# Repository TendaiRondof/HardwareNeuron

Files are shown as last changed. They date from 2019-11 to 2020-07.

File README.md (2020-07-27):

# HardwareNeuron
Eine Brufsmaturitätsarbeit für die BBW Winterthur.

## Abstract
### Deutsch
In dieser BMA stellen wir, Tendai und Malik, uns die Frage, ob es möglich ist, mit simplen elektronischen Bauteilen eine Schaltung zu entwerfen, die bestimmte, elementare Logik erlernen und anschliessend wiedergeben kann. Um dies zu erreichen, verwenden wir das Modell eines Neurons. Wir erläutern Struktur und Funktion des biologischen und des informatischen Modells. Schliesslich fällt unsere, ausführlich begründete Entscheidung auf das spiking neural Network. Das die Version des informatischen Modells, welches dem bioligischen am nächsten kommt. Danach nähern wir uns mittels mathematischen Formeln, basierend auf dem spiking neural Network, den Funktionen an, welche die Schaltung erfüllen muss. Darauffolgend werden die Teilfunktionen erklärt und es wird erläutert, wie unsere Schaltung sie bewältigen soll. Die Messungen des Prototypen zeigen, dass die Vorwärtsrechnung, also das wiedergeben des gelernten, funktioniert. Das Problem ist, dass bei unserem Endprodukt nichts funktioniert, da die Leiterbahnen auf dieser Version sehr kurzschlussanfällig sind und wir keine Zeit mehr hatten, alle Kurzschlüsse zu beheben.
### English
In this BMA we, that’s Malik and Tendai, ask ourselves, wether or not it’s possible, to design an electrical circuit, which can learn certain, elementary logic and replicate it subsequently. In order to reach this, we use the model of a neuron. We explain structure and function of the biological and informatical model. In the end, our decision falls onto the spiking neural network. That’s the informatical model, which comes closest to the biological one. Then, we draw up the functions, that our circuit has to implement, through mathematical formulas. After that, the purposes of the smaller subcircuits, we designed, is explained. In the measurements of the Prototype it is shown, that the replication of logic works. Unfortunately the learning itself doesn’t. Besides of that, our final product doesn’t work at all, because there are shortcircuits all over the print and we didn’t have time, to repair them all.

Von Tendai Rondof und Malik Schneider

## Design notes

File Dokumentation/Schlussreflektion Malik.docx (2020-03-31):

Schlussreflektion zur BMA Hardware Neuron

Ich war mit dieser BMA bereits überfordert, als es noch um die Themenwahl ging. Ich wusste, dass wir wahrscheinlich ungefähr 100 Stunden in dieses Projekt stecken müssten, um es befriedigend fertigzustellen.

Das Thema würde also von riesigem Gewicht sein. Wer will sich schon 100 Stunden mit etwas auseinandersetzen, was ihn nicht interessiert. Das erste Mal, als wir uns für ein Thema entschieden, kamen wir auf das Thema Videospiele und ihre Physik. Diese wollten wir in unserem Projekt analysieren. Wir haben uns nach einer Zeit aber dagegen entschieden, da wir dachten, dass diese Arbeit zu nichts führen würde.

Dann begannen wir die Arbeit am eigentlichen BMA-Projekt: dem Hardware Neuron. Die Idee war eine elektrische Schaltung zu entwickeln, welche die Lernprozesse eines Neurons nachahmen konnte. Wir entschieden uns dafür, weil es ein festes Ziel war, was wir anstreben konnten und es uns interessierte. Ich denke nach wie vor, dass es die richtige Entscheidung war, aus den zuvor genannten Gründen.

Der Zeitplan, den wir erstellt hatten, wurde in den ersten Monaten sehr gut eingehalten. Wir waren sogar ein grosses Stück vor dem Zeitplan. Das war, als wir das Schema der Schaltung im Prinzip vollendet hatten und dachten, wir könnten uns jetzt ausruhen. Jetzt wissen wir jedoch, dass es am besten gewesen wäre, gleich erste Prototypen zu erstellen. Wir starteten damit nämlich erst knapp einen Monat vor der Abgabe. Und konnten auch nur am Wochenende daran arbeiten. Das bedeute für uns, vier Wochen lang keinen einzigen freien Tag. Trotz diesen Anstrengungen, reichte die Zeit am Ende dann doch nicht. Das war sehr ärgerlich. Dafür haben wir unsere Arbeit ziemlich gut dokumentiert, meiner Meinung nach. Wir konnten alle Vorgänge des Neurons erklären und die Annäherung vom Modell zur Schaltung ist ausführlich und klar. Auch die Gesamtstruktur mit allen nötigen Verzeichnissen ist vorhanden.

Obwohl unser Produkt nicht den geplanten Endstatus erreicht hat, bin ich gesamthaft gesehen mit unserer BMA zufrieden.

Malik Schneider 11.02.2020

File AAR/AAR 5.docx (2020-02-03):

# 15 minütiges After Action Review

# 1. Was sollte erreicht werden? (Sollzustand/Ziel: anspruchsvoll, aber realistisch, konkret) [1 Minute]

Funktionierender Print der Neuronschaltung, schriftlicher Kommentar vollständig

# 2. Was haben wir (nicht) erreicht? (Istzustand: kurz, präzise, vollständig) [2 Minuten]

Schriftlicher Kommentar vollständig, Print funktioniert nicht lediglich der Prototyp in begrenztem Masse

# 3. Warum haben wir es (nicht) erreicht? (Abweichungsanalyse: selbstkritisch, vielfältig) [4 Minuten]

In den letzten paar Wochen haben wir am Prozess und in der Planung nichts falsch gemacht. Wir haben uns die wenige Zeit die wir hatten klar eingeteilt. Leider ist die Bestellung des letzten Prints nicht planungsgemäss angekommen und und der Print den wir deswegen selber in der MSW machen mussten nahm viel zu viel Zeit in Anspruch, funktionierte am Ende dann aber doch nicht. Es wäre zwar möglich gewesen, ihn zu reparieren, aber dafür hatten wir dann endgültig keine Zeit mehr.

# 4. Was können wir daraus lernen? (Handlungsmassnahmen: konkret, realistisch, ausgearbeitet) [8 Minuten]

Wir können daraus lernen, dass man eine solch gigantische Arbeit mit viel Zeitreserven planen sollte.Vor allem bei einem Produkt mit dieser Komplexität.

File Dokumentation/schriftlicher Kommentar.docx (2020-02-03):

Berufsmaturitätsarbeit 2019-2020

Hardware-Neuron

Tendai Rondof / Malik Schneider

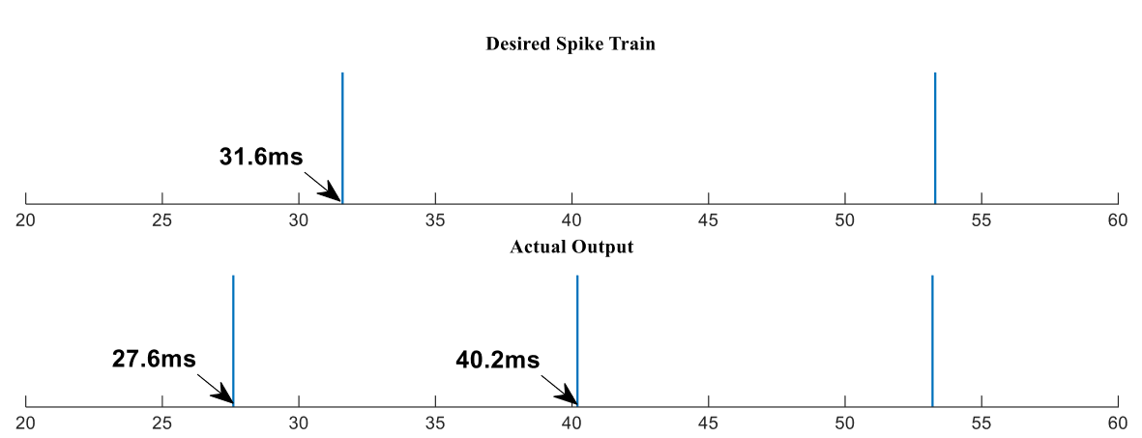
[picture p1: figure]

S(t)

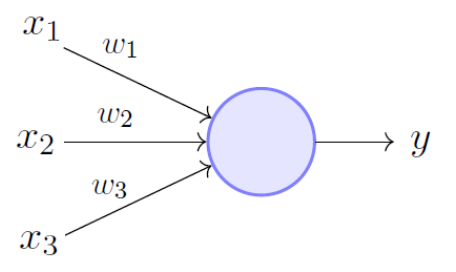
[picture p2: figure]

U_a (t)

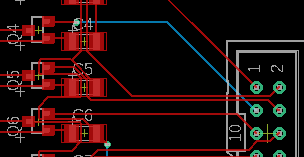
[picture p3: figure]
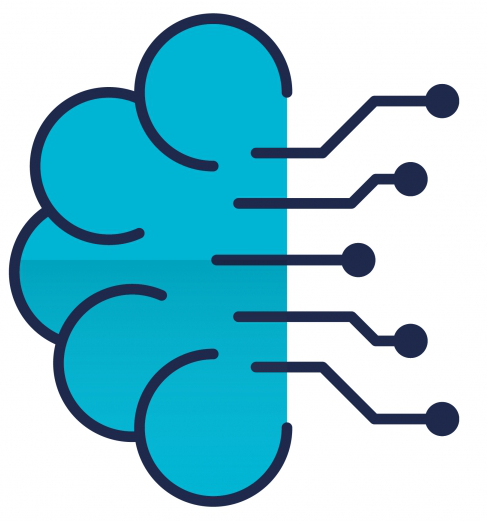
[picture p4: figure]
Bildergebnis für artificial intelligence icon

# Vorwort

Seit einiger Zeit boomt das Interesse an künstlichen Intelligenzen und neue Ideen, wie sie umgesetzt werden können, sind hochgefragt. Wir erwarten nicht dass wir mit einem Analogen Neuron das Rad neu erfinden, jedoch gelingt es uns einen Weg zu beschreiten der bis jetzt noch niemand gedacht hat.

## Tendai

Ich habe dieses Thema ausgewählt, weil Künstliche Intelligenzen mich seit Jahren interessieren. Durch dieses Projekt kann ich den Wunsch ein Neuron auf Hardwarebasis zu erstellen, endlich erfüllen.

## Malik

Ich habe das Thema gewählt, weil darin zwei meiner grössten Interessensgebiete vereinigt sind: Die Elektronik und die Neurowissenschaft. Vor allem bei letzterem kann ich hiermit mein Wissen erweitern und vertiefen. In der Elektronik kann ich vor allem mein bereits bestehendes Wissen anwenden und trainieren, was meinem späteren Berufsleben ein wenig zu gute kommen könnte.

## Danksagungen

Wir möchten unserem Abteilungsleiter, Oliver Schneider, in der MSW danken, welcher uns erlaubte an den Wochenenden in der MSW an unserer BMA zu arbeiten. Ohne seine Hilfe hätten wir unser Produkt sicher nicht rechtzeitig beenden können.

Daniel Büchler, Abteilungsleiter für die ersten beiden Lehrjahre der Elektroniker in der MSW hat uns freundlicherweise den Fräsbohrplotter zu Verfügung gestellt. Dieser Umstand hat unsere Arbeit ungeheuer beschleunigt.

# Abstract

# Einleitung

Das Ziel unserer BMA ist es, den Vorgang des Lernens mit greifbaren elektrischen Bauteilen zu simulieren. Dieser Aspekt allein hat schon eine gewisse Faszination an sich. Unter Machine-Learning versteht man etwas extrem Komplexes, was sich auf Softwareebene abspielt. Für eine Künstliche Intelligenz sind riesige Mengen an Daten Nötig um ihr etwas beizubringen. Aber wie so vieles, lässt sich auch eine Intelligenz, ob sie jetzt künstlich ist oder nicht, herunterbrechen auf ihre Elementarsten Teile. Beim Menschen sind es die Neuronen, bei der Maschine elektrische Schaltkreise. Unser Produkt ist ein wenig von beidem. Denn wir simulieren das menschliche Neuron mit einer elektrischen Schaltung.

Aufgrund unseres Lehrberufs, Elektroniker, setzten wir den Fokus auf die Funktionalität und nicht auf Biologische Richtigkeit. Das bedeutet, dass wir versuchten die chemischen Prozesse elektronisch zu imitieren. Es fielen zwar viele der Biologischen Aspekte eines Neurons weg, jedoch bleibt der Kern des ganzen schlussendlich bestehen: das Lernen.

Um die Printplatte herzustellen, auf welcher wir unsere Schaltung aufgebaut haben, verwendeten wir den MSW-Internen Fräsbohrplotter, welcher uns die ersten Prototypen in höchstgeschwindigkeit zur Verfügung stellen konnte.

Die Frage die wir uns mit dieser BMA beantworten wollen lautet:

Was ist eine Möglichkeit ein Neuron (Nervenzelle) mittels Elektronischen teilen zu realisieren und kann damit eine selbstlernende elektrische Schaltung (“Neuron”) erstellt werden?

Um diese Frage dreht sich die ganze Arbeit unserer BMA. Darum auch der Name Hardware-Neuron. Unser Endprodukt wird Ausschlisslich aus Elektronischer Hardware bestehen. Mit unserem Endprodukt werden wir uns den ersten Teil der Frage also selbst beantworten.

Zu Beginn des Hauptteils wird das Konzept zur Lösung des Problems in all ihren Details und mathematischen Formeln erklärt. Danach wird die Schaltung erklärt, die wir erstellt haben und nach den zuvor erläuterten Funktionen arbeitet. Darauf folgen das Design des Prints auf EAGLE und die Auflistung der Bauteile welche auf den Print gehören.

# Hauptteil

# Theorie

## Grundlage der Problematik

Es soll eine Schaltung erstellt werden, die Mathematische Berechnungen eines Neurons imitiert. Dadurch kann eine lernende Schaltung entwickelt werden, die dynamische bzw. lernende Schaltkreise ermöglichen. Zudem wird die Rechenzeit für ein Neuron reduziert.

Als lernen ist zu verstehen, dass die Schaltung berechnet, wie sie welche Eingänge verarbeiten soll. Das passiert, indem der Nutzer am Eingang Daten anlegt und gleichzeitig einen Sollwert für den Ausgang definiert. Mit der Zeit lernt also die Schaltung, wie sie die Eingangsdaten verarbeiten soll und wie sie darauf reagieren soll.

## Testbedingungen

Damit das Folgende auch gut verstanden werden kann, eine kurze Erklärung zu den Fachbegriffen. In der Elektronik bzw. Digitaltechnik wird mit dem Binären Zahlensystem gearbeitet, diese Zahlen werden aus Einsen und Nullen gebildet.

Jede 0/1 hat einen Zahlenwert den sie repräsentiert. Im binärsystem wird die Wertung von rechts nach links pro Stelle verdoppelt. D.h. die erste Ziffer von rechts steht eins, die zweite für zwei, die dritte für 4 usw.. Steht eine Eins an der Stelle wird die jeweilige Wertung dazu addiert, steht da eine Null, dann nicht.

Bsp.:

0001 entspricht im Dezimalsystem der Zahl 1. Weil: (0*8)+(0*4)+(0*2)+(1*1)=1

0010 entspricht der Zahl 2. Weil: (0*8)+(0*4)+(1*2)+(0*1)=2

0011 entspricht der Zahl 3. Weil: (0*8)+(0*4)+(1*2)+(1*1)=3

0100 entspricht der Zahl 4. Weil: (0*8)+(1*4)+(0*2)+(0*1)=4

Usw.

In der Praxis entspricht die 1 einer Spannung von 5 Volt (auch «High» genannt) und die 0 einer Spannung von 0V (auch «Low» genannt).

Um diese Informationen in der Elementarsten weise zu verarbeiten werden Drei Grundgatter verwendet:

AND:

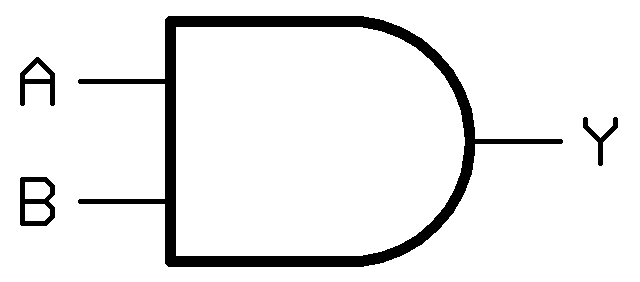
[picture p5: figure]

(Quelle : https://de.wikipedia.org/wiki/Datei:Logic-gate-and-us.png)

A | B | Y
0 | 0 | 0
0 | 1 | 0
1 | 0 | 0
1 | 1 | 1

Das AND-Gate verknüpft die Eingänge (A & B) so, dass der Ausgang (Y) nur einem «High» entspricht, wenn die A und B zur gleichen zeit auch «High» sind. Jede andere Kombination führt zu einem «Low» am Ausgang.

OR:

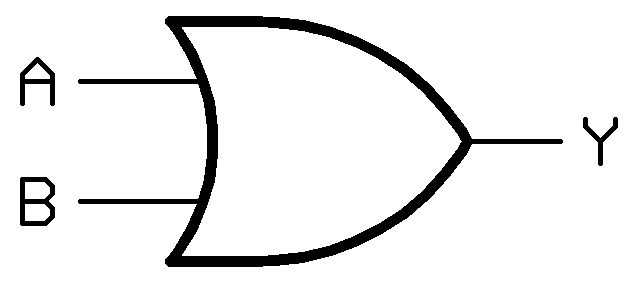
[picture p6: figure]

(Quelle : https://de.m.wikipedia.org/wiki/Datei:Logic-gate-or-us.png)

A | B | Y
0 | 0 | 0
0 | 1 | 1
1 | 0 | 1
1 | 1 | 1

Das OR-Gate verknüpft die Eingänge (A & B) so, dass der Ausgang (Y) einem «High» entspricht, wenn mindestens einer der Beiden Eingänge «High» ist.

NOT:

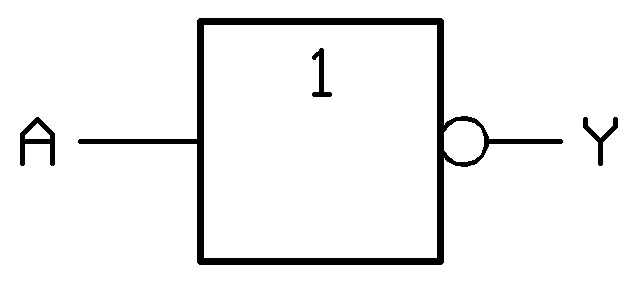
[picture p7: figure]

(Quelle : https://de.wikipedia.org/wiki/Datei:Logic-gate-inv-iec.png)

A | Y
0 | 1
1 | 0

Das NOT-Gate besitzt nur einen Eingang (A). Das Gatter macht nichts anderes, als das Gegenteil vom Eingang auszugeben.

### Möglichkeiten

Um zu überprüfen ob das Neuron auch lernt, soll es die Aufgabe von logischen Gattern (AND, OR) übernehmen bzw. lernen. Um zu überprüfen, ob das Neuron in der Lage ist zu merken, wenn ein Eingang nicht benötigt wird, wird neben den notwendigen Eingängen auch noch ein überflüssiger Eingang benutzt, der Ignoriert werden soll. Wenn dies zuverlässig funktioniert, kann man davon ausgehen, dass das Neuron in der Lage ist, bedingt komplexe Zusammenhänge zu approximieren und wichtige von nicht wichtiger Information zu unterscheiden.

### Unmöglichkeiten

Da das Neuron auf keinen Fall in der Lage ist Invertierungen (NOT-Gatter) zu imitieren, sind Kombinationen auf der Basis: «Wenn ein Eingang nicht eingeschaltet ist, dann…». Von vorherein ausgeschlossen und unmöglich für das Neuron zu erlernen.

Um es in technischer Sprache zu sagen, das Neuron ist nicht in der Lage XOR, XNOR, NAND, NOR oder NOT Gatter zu erlernen, da nach dem Aufbau des Eingangs (Inputs) immer ein Stromzufluss herrschen muss.

## Grundlegendes Model eines Neurons

### Biologisch

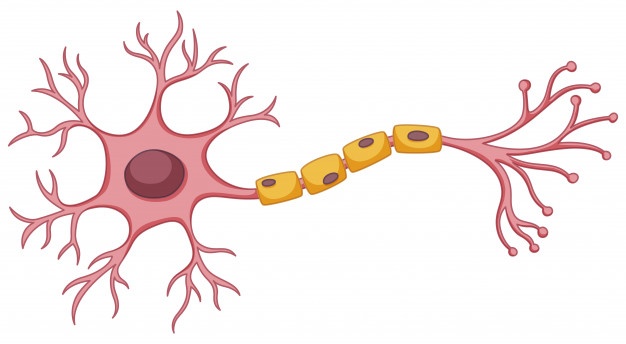
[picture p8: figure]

Abbildung 1

Das Neuron ist eine Nervenzelle, die nahe zu überall in unserem Körper vorhanden ist. Ihr wichtigster Einsatzort ist das Gehirn.

## Bedingungen/Einschränkungen

Es gibt gewisse Probleme bei der Übersetzung vom Modell in die reale Welt. Zum einen ist die Praxis nie perfekt. Bauteile haben Toleranzen, Unendlichkeiten gibt es nicht und es ist nicht möglich Spannungen auf eine einfache Art und Weise zu multiplizieren.

Die gewünschte Formel wird auch nicht in einer reinen Form vorkommen.

## Typ des Neurons (Vorteile gegenüber anderen Methoden)

Als Grundprinzip benutzen wir das Modell eines Spiking-Perceptrons, was ein einzelnes Neuron mit einem pulsierenden, digitalen Ausgang darstellt.

Der Vorteil gegenüber anderen Methoden ist, es kommt der Biologie am nächsten und die Rückrechnung ist mit einzelnen Transistoren machbar.

Der Nachteil ist, es ist zeitabhängig. Was bedeutet, dass zeitlich alles gut aufeinander abgestimmt sein muss.

## Mathematischer Ansatz vorwärts Rechnung

Die Grundformel für den Kern des Neurons ist:

C(dU_c (t))/(dt)=-(U_c (t))/(R_0)+(∑_i^n (U_(x_i) (t))/(R_(T_i) (U_(c_(T_i)) (t))))+I_(bias) (t)-(U_c (t))/(R_(disc) (U_a (t)))

(Formel 1) Quelle: 7146.pdf

U_c :Die spannung am Kernkondensator

C:Kapazität des Kernkondensators

R_0 :Entladungs Widerstand am Kernkondensator

n:Anzahl eingänge

U_(x_i) :Sapnnung Am eingang i

R_(T_i) :Funktion des Transitor-Widerstands in abhängikeit der Spannung U_(c_(T_i))

U_(c_(T_i)) : Spannung des Kondensators am Gate des Transitors

I_(bias) :Strom des Statischen 5V eingangs

R_(disc) : Widerstand des Entladungstransitors

Wenn der Kern-Kondensator eine Gewisse Spannung (U_(ref) ) erreicht wird ein «Spike» erzeugt, was am Ausgang ausgegeben wird. Dieser «Spike» wird durch eine Aktivierungsfunktion erzeugt.

## Aktivierung

Y(t)= d/(dt)(max(U_c (t),U_(ref) )*V_(cc) )

U_c :Kernkondensator Spannung

U_(ref) :Statische Referenz Spannung

V_(cc) :Speise Spannung des Prints

Y : Ausgabe der Schaltung

Sobald der Spike erzeugt wird, wird U_c über den Discharge-Transitor auf 0V gezogen. Was zur Folge hat, dass wenn der Input dauerhaft auf 5V gestellt ist, sich ein «Spike Train» mit einer Festen Frequenz bildet.

## Fehlerberechnung

Damit das Neuron überhaupt etwas lernt, muss eine Art Feedback vom Nutzer oder von der Umgebung kommen. Dafür wird ein Rückgabewert ( S ) verwendet. Mit diesem Rückgabewert kann die Gewichtung 1/(R_(T_i) (U_(c_(T_i)) (t))) angepasst werden, indem U_(c_(T_i)) verändert wird.

(dU_(c_(T_i)) (t))/(dt)=1/(V_(cc)^2 *R_(LR))*U_(X_i) (t)*|S(t)-Y(t)|*(|S(t)-Y(t)|-U_(c_(T_i)) )

(Bild 2) Quelle: 7146.pdf

U_(c_(T_i)) : Spannung des Kondensators am Gate des Transitors

C_(T_i) : Kondensator am Gate des Transistors

U_(x_i) : Spannung am Eingang i

R_(LR) : Widerstand der die Ent-/Lade Geschwindigkeit des Kondensators C_(T_i) angibt (Lern- Schrittgeschwindigkeit)

V_(cc) :Speise Spannung des Prints

S : Ziel Spike-Train, dass das Neuron erreichen soll

Da S und Y zeitbegrenzte Pulse sind, wird der Kondensator nur ein klein wenig entladen/geladen was den Transistor am jeweiligen Eingang etwas mehr sperrt oder leitet. Dadurch können alle Inputgewichte über die Zeit so eingestellt werden, dass S(t) dem Ausgang U_a (t) entspricht.

Dies ist natürlich nur bis zu einer gewissen Komplexität möglich. Vor allem, da die Eingangsströme nicht negativ sein können.

## Problematik von Theorie und Praxis

Die Grösste Problematik ist, dass das Speichern von Analogen Spannungen nur sehr schlecht geht und sehr störungsanfällig ist. Man kann die Schaltung etwas Stabilisieren, indem man den Print so gut wie möglich isoliert um jeglichen Energieverlust über benachbarte Leitungen zu vermeiden.

## Blockschaltbild

Output

Schaltung

Stecker

- 3 Eingänge

- Sollwert für Output

- Rückrechnung Ein/Aus

Abbildung 2

# Erklärung der Funktion

## Ganzes Neuron

Abbildung 3

Der Eingang (Input) verarbeitet die Spannung an den Eingängen X_0 bis X_2 und summiert sie. Das Zentrum (Core) des Neurons speichert die Werte des Eingangs über die Zeit, bis die Aktivierung (Activation) einsetzt und das Zentrum zurückgesetzt wird.

Der Eingang S bei der Fehlerberechnung (DeltaCalcV2) entspricht dem Sollwert zu Trainingszeiten. Der Ausgang Y bei der Aktivierung wird zu jedem Zeitpunkt beim Training mit dem Sollwert mittels der Fehlerberechnung verarbeitet und der Eingang angepasst.

Das Neuron lernt somit über Zeit und der Eingang wird bei jedem Fehler um einen konstanten minimalen Schritt-Wert angepasst, um ein Schwingen um den Idealwert zu vermeiden und um das Neuron robuster gegen einzelne Fehler in den Trainingsdaten zu machen.

## Input

Abbildung 4

Die Eingangsspannungen X_0 bis X_2 werden über die, zum Teil leitenden, Transistoren in spezifische Ströme umgewandelt und am Ausgang summiert.

Die Spannungen an den Kondensatoren bestimmen, wie stark die Transistoren durchsteuern. So kann der Widerstand der Transistoren kontrolliert werden. Die Spannung an den Kondensatoren wird über die Fehlerberechnung verändert.

Im mathematischen Sinne entspricht diese Teilschaltung dem Abschnitt

(∑_i^n (U_(x_i) (t))/(R_(T_i) (U_(c_(T_i)) (t))))+I_(bias) (t)

Aus der Formel für die Vorwärtsrechnung.

Der I_(bias) (t) kommt von dem Transistor Q_7 , der direkt an V_(cc) angeschlossen ist.

### DeltaApply

Abbildung 5

Diese Teilschaltung ist für das Anpassen der Spannungen am Kondensator zuständig. Jeder Eingang besitzt eine solche Teilschaltung. Der Eingang Delta bestimmt, ob der Core-Kondensator geladen oder entladen wird. Enable schaltet mit der Spannung am Transistor den Rückrechnungsvorgang ein oder aus. Der Eingang X sagt der Schaltung, ob der Eingang der Gesamtschaltung überhaupt aktiv war.

Diese Teilschaltung ist die Umsetzung des Formelabschnittes 1/(V_(cc)^2 *R_(LR))*U_(X_i) (t)*E*(D-U_(c_(T_i)) ) , wobei E dem Enable-Eingang, U_(X_i) dem Eingang X und D dem Delta Eingang entspricht.

## Core

Abbildung 6

Der Core besteht hauptsächlich aus einem Kondensator C , welcher über den Eingang a aufgeladen wird. Für den Fall, dass keine Signale über die Eingänge X_0 bis X_2 kommen, sorgt der Widerstand R dafür, dass sich der Kondensator langsam entlädt und nach einer gewissen Zeit der Kondensator wieder zurückgesetzt ist.

Die Mathematische Darstellung der Teilschaltung ist C(dU_c (t))/(dt)=-(U_c (t))/(R_0)+a . Dabei entspricht a dem Ausgang der Input-Teilschaltung.

## Activation

Abbildung 7

Die Aktivierung ist dazu da, um zu bestimmen ob ein Signal weiter bzw. ausgegeben werden soll. Wenn die Spannung am Core (Kondensator) über die 2.5V steigt, schaltet der Vergleicher von 0V auf 5V über eine sehr kurze Zeit. Durch diese rapide Änderung gibt es eine Spannungsspitze auf der anderen Seite des Kondensators. Diese Spannungsspitze wird über die zwei folgenden Transistoren verstärkt, damit das Ausgangssignal eine höhere Spannung erreicht und auch mehr Strom liefern kann.

Dieses Ausgangssignal wird über die Grüne Leiterbahn zurückgeführt und entlädt den Core (Kondensator) sehr schnell. Wodurch dieser wieder auf unter die 2.5V fällt und der Ausgang des Vergleichers wieder auf 0V schaltet. Danach beginnt der Vorgang von vorne.

Die Diode am Ausgang sorgt dafür, dass wenn der Ausgang des Vergleichers auf 0V ist, der Ausgang der Ganzen Schaltung einen «Tri-state» annimmt (Das bedeutet, dass kein Strom rückwärts in die Schaltung fliessen kann).

### Vergleicher OPV

Abbildung 8

Dies ist eine primitive Schaltung eines Komparators bzw. Vergleicher, welcher in der Elektronik eine Essentielle Rolle spielt. Er vergleicht die Eingänge + & – und schaltet den Ausgang auf 5V, wenn die Spannung am + Eingang Grösser ist als die am – Eingang. Ist das umgekehrte der Fall wird der Ausgang auf 0V gesetzt.

## DeltaCalc

Abbildung 9

Die Delta-Calculation (DeltaCalc) ist dafür zuständig, zu entscheiden, ob der Ausgang (Ist-Wert) mit dem Soll-Wert übereinstimmt. Der Ausgang «Delta» von diesem Abschnitt gibt an, ob die Kondensatoren an den Eingängen X_0 bis X_3 geladen oder entladen werden sollen. Der Ausgang «En» (Kurz für Enable) von diesem Abschnitt sagt ob dieses Laden oder Entladen der Kondensatoren überhabt durchgeführt werden soll oder nicht.

In Digital-technischer Sprache:

Der Ausgang «Delta» entspricht einem Und Gatter mit den Eingängen ¬S und Y . Der Ausgang «En» ist eine XNOR Verknüpfung von S und Y . Sprich wen S=Y dann sollen keine Änderungen an den Kondensatoren vorgenommen werden.

# Detailiertes Gesamtschema von EAGLE

Abbildung 10

# Messungen

## Blockschaltbild des Versuchsaufbaus

Mikro-kontroller

Schaltung

3Eingänge & Sollwert Sollwert

Istwert

Abbildung 11

Der Mikrokontroller ist so programmiert, dass in einem 10kHz Tackt hochgezählt wird und der momentan Wert, an den 3 Eingängen in binärer Form und den Sollwert mittels einer logischen Verknüpfung, an die Schaltung übertragen wird. Danach wird der Istwert der Schaltung vom Mikrokontroller eingelesen und abgespeichert. Pro Verknüpfung werden 100 Trainingsdurchläufe durchgeführt. Somit dauert ein Lerndurchgang ca. 70ms. Dies wird für die Verknüpfungen AND und OR durchgeführt und mehrmals nach einem Neustart der Schaltung wiederholt.

## Programmierung des Mikrokontrollers

# Benutzeranleitung

# Abkürzungsverzeichnis

- EAGLE einfach anwendbarer Grafischer Layout Editor

Wir haben dieses Programm verwendet, um darin unser Schema zu zeichnen und den Print zu designen

# Anhang

## Layout/Bestückungsplan von EAGLE

## Stückliste

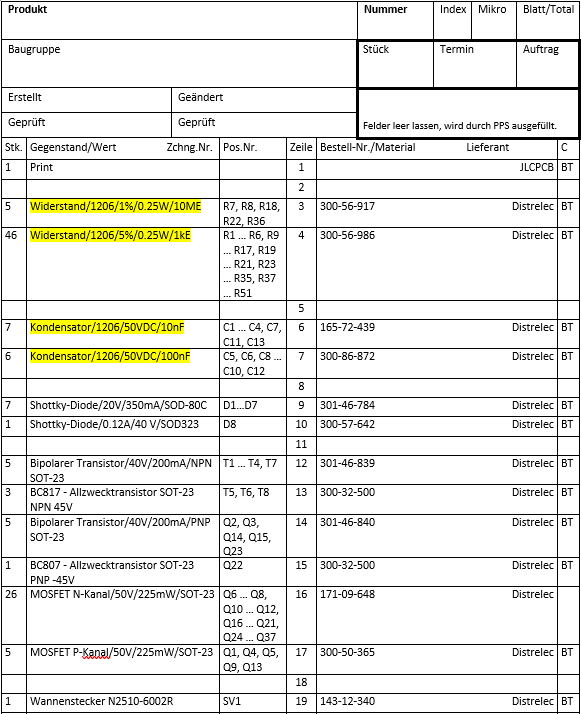
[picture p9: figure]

Betreuende Lehrperson: M.Mohr

Berufsbildungsschule BMS / 7a / technische Richtung Abgabedatum Winterthur

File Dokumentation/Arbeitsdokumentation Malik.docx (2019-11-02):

Kommunikation mit TUHH

29.9.2019

Die Kommunikation mit der TUHH war meiner Ansicht nach eine etwas zähe Angelegenheit. Zum Zeitpunkt dieses schreibens sind wir auch noch nicht zu einer gemeinsamen Einigung gekommen. Das Ziel war für mich, dass wir in Hamburg etwas haben, dem wir nachgehen können und das sich auf unsere BMA bezieht. Bei nicht erfüllen dieses Ziels, wäre die Projektwoche für den Prozess unserer BMA ja völlig irrelevant. Darum werde ich versuchen, vor der Projektwoche zumindest noch einmal Kontakt mit der Institution aufzunehmen.

Layouten der elektrischen Schaltung

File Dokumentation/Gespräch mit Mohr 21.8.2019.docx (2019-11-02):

1. Abklärung der Machbarkeit mittels literaturrecherche
  a. https://www.instructables.com/id/Construct-a-Synthetic-Neural-Network/: In the beginning of this year (2015) I finished building and testing a single asynchronous digital neuron (https://www.instructables.com/id/Asynchronous-Digital-Neuron/). I've now finished building a network of 36 of them. Most of this work has been in building the support hardware for the synthetic neural network. Training the network is going to be another several months of work, of course, and the subject of future writing. The build cost was low: c < $150 for me (I used scavenged parts for the case and the fancy giant switch). $200 or less estimated cost for someone who already owns a soldering iron and wire. The device is an asynchronous neural network in a tiny synthetic universe. It also contains a connectome control module with which to design learning algorithms. Build and debugging time for me to reach this point with this specific device -- starting from nothing -- was about 200 hours according to my time log.
  b. https://neil.fraser.name/hardware/neuron/: Dieser Blog beschreibt wie Neil Fraser eine schaltung entwickelt hat die ein Neuron Repräsentiert das ihre gewichtungen MANUELL von einem Menschen bekommt.
2. Genauere Funktionsbeschreibung
- 8 Eingänge (Digital)
- 1 Ausgang (Analog)
- “Blackbox”-artige Funktionsweise
- Relation von Ausgang zu Eingang kann, durch überwachtes lernen, während der Laufzeit verändert werden.
3. Überarbeitung der Fragestellung
  a. zu erfüllende Bedingungen
    i. supervised learning
    ii. auf basis von Neuronaler KI
    iii. Rein Hardware
    iv. fähig ein problem zu lösen
    v. nicht linear
    vi. eine möglichkeit von vielen
  b. neuer Fragestellung: Wie ist ein überwacht lernendes Neuron allein mit elektrischer Hardware realisierbar?
4. Was ist gemeint mit grossem Potenzial und nicht genutzt?
5. Was heisst dto?
6. Keine weiter erläuterte Kritik zum Zeitmanagement
7. Konzept überarbeiten
8. Vortrag an TUHH
9. genaue Zeiten wegen Projektwoche?

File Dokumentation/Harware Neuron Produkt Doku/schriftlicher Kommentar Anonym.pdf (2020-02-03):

## Berufsmaturitätsarbeit 2019-2020

# Hardware-Neuron

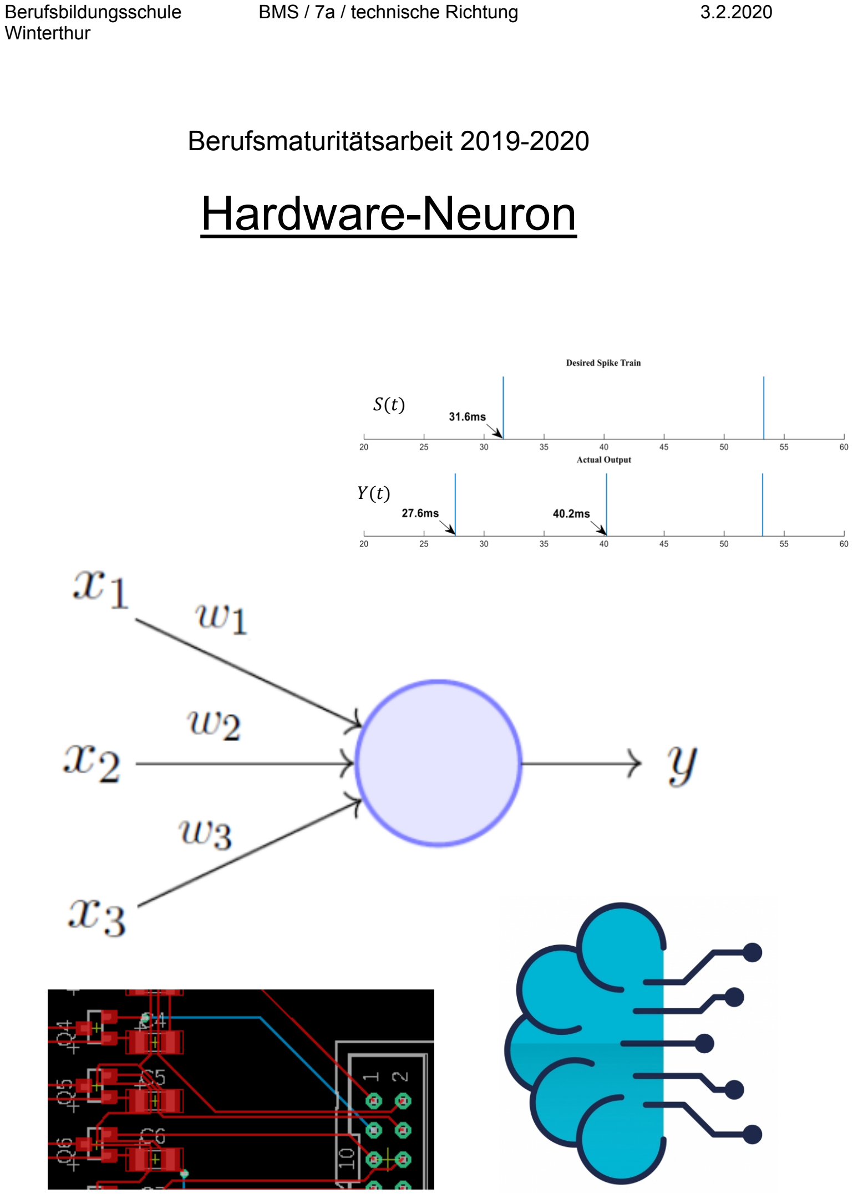
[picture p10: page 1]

Berufsbildungsschule | BMS / 7a / technische Richtung | 3.2.2020
Winterthur

S(t)

Y(t)

## I. Inhaltsverzeichnis

## II. Vorwort

Seit einiger Zeit boomt das Interesse an künstlichen Intelligenzen und neue Ideen, wie sie umgesetzt werden können, sind hochgefragt. Wir erwarten nicht dass wir mit einem Neuron, dass aus einem elektronischen Schaltkreis besteht, das Rad neu erfinden, jedoch gelingt es uns vielleicht einen Weg zu beschreiten der bis jetzt noch niemand bedacht hat.

A. Gruppenmitglied 1
Ich habe dieses Thema ausgewählt, weil Künstliche Intelligenzen mich seit Jahren interessieren. Durch dieses Projekt kann ich den Wunsch ein Neuron auf Hardwarebasis zu erstellen, endlich erfüllen.
A. Gruppenmitglied 2
Ich habe das Thema gewählt, weil darin zwei grosse Interessensgebiete von mir vereinigt sind: Die Elektronik und die Neurowissenschaft. Vor allem bei letzterem kann ich hiermit mein Wissen erweitern und vertiefen. In der Elektronik kann ich vor allem mein bereits bestehendes Wissen anwenden und trainieren, was meinem späteren Berufsleben ein wenig zugutekommen könnte.
B. Danksagungen
Wir möchten unserem Abteilungsleiter, in unserem Lehrbetrieb danken, welcher uns erlaubte, an den Wochenenden in unserem Lehrbetrieb an unserer BMA zu arbeiten. Ohne seine Hilfe hätten wir unser Produkt sicher nicht rechtzeitig beenden können.

Abteilungsleiter für die ersten beiden Lehrjahre der Elektroniker in unserem Lehrbetrieb hat uns freundlicherweise den Fräsbohrplotter zu Verfügung gestellt. Dieser Umstand hat unsere Arbeit ungeheuer beschleunigt. Vor allem für die endgültig letzte Version des Prints war diese Maschine unentbehrlich, weil der bestellte Print aus dem Ausland zu spät
angekommen ist.

## III. Abstract

A. Deutsch
In dieser BMA stellen wir, uns die Frage, ob es möglich ist, mit simplen elektronischen Bauteilen eine Schaltung zu entwerfen, die bestimmte, elementare Logik erlernen und anschliessend wiedergeben kann. Um dies zu erreichen, verwenden wir das Modell eines Neurons. Wir erläutern Struktur und Funktion des biologischen und des informatischen Modells. Schliesslich fällt unsere, ausführlich begründete Entscheidung auf das spiking neural Network. Das die Version des informatischen Modells, welches dem bioligischen am nächsten kommt. Danach nähern wir uns mittels mathematischen Formeln, basierend auf dem spiking neural Network, den Funktionen an, welche die Schaltung erfüllen muss.

Darauffolgend werden die Teilfunktionen erklärt und es wird erläutert, wie unsere Schaltung sie bewältigen soll. Die Messungen des Prototypen zeigen, dass die Vorwärtsrechnung, also das wiedergeben des gelernten, funktioniert. Das Problem ist, dass bei unserem Endprodukt nichts funktioniert, da die Leiterbahnen auf dieser Version sehr kurzschlussanfällig sind und wir keine Zeit mehr hatten, alle Kurzschlüsse zu beheben.

B. English
In this BMA we, ask ourselves, wether or not it’s possible, to design an electrical circuit, which can learn certain, elementary logic and replicate it subsequently. In order to reach this, we use the model of a neuron. We explain structure and function of the biological and informatical model. In the end, our decision falls onto the spiking neural network. That’s the informatical model, which comes closest to the biological one. Then, we draw up the functions, that our circuit has to implement, through mathematical formulas. After that, the purposes of the smaller subcircuits, we designed, is explained. In the measurements of the Prototype it is shown, that the replication of logic works. Unfortunately the learning itself doesn’t. Besides of that, our final product doesn’t work at all, because there are shortcircuits all over the print and we didn’t have time, to repair them all.

## IV. Einleitung

Das Ziel unserer BMA ist es, den Vorgang des Lernens mit greifbaren, elektronischen Bauteilen zu simulieren. Dieser Aspekt allein hat schon eine gewisse Faszination an sich. Unter Machine-Learning versteht man etwas Komplexes, was sich auf Softwareebene abspielt. Für eine Künstliche Intelligenz sind riesige Mengen an Daten nötig, um ihr etwas beizubringen. Aber wie so vieles, lässt sich auch eine Intelligenz, ob sie jetzt künstlich ist oder nicht, herunterbrechen auf ihre Elementarsten Teile. Beim Menschen sind es die Neuronen, bei der Maschine elektrische Schaltkreise. Unser Produkt ist ein wenig von beidem; Wir simulieren das menschliche Neuron mit einer elektrischen Schaltung.

Aufgrund unseres Lehrberufs, Elektroniker, setzten wir den Fokus auf die Funktionalität und nicht auf Biologische Richtigkeit. Das bedeutet, dass wir versuchten die Funktion elektronisch zu imitieren. Es fielen zwar viele der Biologischen Aspekte eines Neurons weg, jedoch bleibt der Kern des ganzen schlussendlich bestehen: das Lernen.

Um die Printplatte herzustellen, auf welcher wir unsere Schaltung aufgebaut haben, verwendeten wir den Lehrbetrieb-internen Fräsbohrplotter LPKF ProtoMat S63, welcher uns die ersten Prototypen in Höchstgeschwindigkeit zur Verfügung stellen konnte. Da wir zum Schluss unserer BMA noch eine letzte Version aus dem Ausland bestellten, welche sich verspätete, mussten wir leider auch diesen noch selbst ausfräsen lassen.

Die Frage, die wir uns mit dieser BMA beantworten wollen, lautet:

Was ist eine Möglichkeit, ein Neuron (Nervenzelle) mittels Elektronischen teilen zu realisieren und kann damit eine selbstlernende, elektrische Schaltung (“Neuron”) erstellt werden?

Um diese Frage dreht sich die ganze Arbeit unserer BMA. Darum auch der Name Hardware-Neuron. Unser Endprodukt wird Ausschliesslich aus Elektronischer Hardware bestehen. Mit unserem Endprodukt werden wir uns die Frage also selbst beantworten.

Zu Beginn des Hauptteils wird das Konzept zur Lösung des Problems in all ihren Details und mathematischen Formeln erklärt. Danach wird die Schaltung erklärt, die wir erstellt haben und nach den erläuterten Funktionen arbeitet. Im Anhang finden sie das Design und das Schema des Prints auf EAGLE¹

sowie die Auflistung der Bauteile, welche auf den Print gehören.

## V. Modelle eines Neurons

In diesem Kapitel Zeigen wir zwei unterschiedliche Modelle eines Neurons in verschiedenen Fachbereichen. Das Kapitel macht verständlich, welche Anforderungen wir an unser Produkt haben und wie wir überprüfen ob diese Anforderungen erfüllt wurden. Dieses Kapitel enthält auch unsere Hypothese, wie diese Anforderungen erfüllt werden können, inklusive den im Voraus ersichtlichen Problemen.

A. Biologisches Model

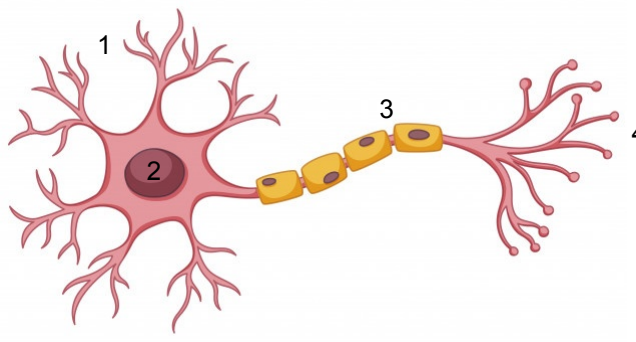
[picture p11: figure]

Das Neuron ist eine Zelle, die auf Signalübertragung spezialisiert ist. Sie kann Reize aufnehmen und ein Signal abgeben. In grosser Zahl und miteinander verbunden, bilden sie das Nervensystem nahezu sämtlicher Säugetiere. Und ihre wohl wichtigste Funktion für uns Menschen ist, dass unser Zentrales Nervensystem (Gehirn) aus ihnen gebaut ist. Nach einer Schätzung etwa neunzig Milliarden²

. Die Signalübertragung geschieht über elektrische

1

EAGLE ist ein Layouteditor, der es ermöglicht, Leiterplatten zu designen Diese Schätzung wurde aus (Wikipedia, 2020) entnommen

Abb 1: Biologisches Neuron (Wikipedia, 2020)

4

Signale, genau genommen über das weiterleiten von Ionensättigungen, und nicht wie bei einer elektrischen Schaltung über einen Elektronenfluss.

In der Abb 1 ist ein solches Neuron Modellgetreu abgebildet. Die Dentriten (Abb 1.1), auch Postsynapse genannt, nehmen die Reize von einem Verhergehenden Neuron oder einer Zelle auf. Der Zellkern/Zellkörper (Abb 1.2) ist das produktions und Speicher Zentrum der Zelle. Dort wird die DNA aufbewahrt, der Stoffwechsel mit der Umgebung durchgefürt und Proteine produziert. Die für uns relevante Funktion dess Zellkerns und des Körpers ist, dass dort die Signale von den Dentriten integrierend³

verarbeitet werden. Über das Axon (Abb 1.3) wird das integrierte Signal nach dem überschreiten eines Threshholds als ein Impuls übertragen und an die Endknöpfchen (Abb 1.4), auch präsynapse genannt, übergeben. Die Endknöpfchen leiten das Signal mittels Neurotransmitter⁴

an ein anderes Neuron weiter. Dieser ganze Durchlauf dauert einige Millisekunden.

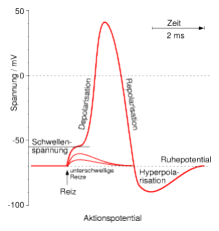
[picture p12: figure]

Abb 2: Aktionspotenzial im Axon (Wikipedia, 2020)
Der Impuls, der das Neuron am Axon empfängt, hat in etwa eine Form wie in Abb 1. In der Abbildung wird auch ersichtlich, wie das Potenzial zuerst in einer e-Kurve vom Ruhepotential ansteigt und ab der Schwellspannung exponentiell bis zu einer Maximalspannung ansteigt, bevor die Spannung wieder zusammenbricht und das Neuron bis zum Wiedererlangen des Ruhepotentials Nichts mehr tun kann.
B. Informatisches Model
Das künstliche Neuron ist eine Struktur, welche dazu in der Lage ist, eine Funktion zu approximieren. Im Grunde hat diese Struktur im Minimum drei Abschnitte, die jeweils zu einem Abschnitt im Biologischen Neuron korrespondieren. Bisher wurden so viele Variationen der einzelnen Abschnitte entwickelt, die immer auf eine Anwendung optimiert sind, dass man sie hier nicht alle auflisten kann. Im Gegensatz zum biologischen Neuron hat das Künstliche Neuron eine Laufzeit von meist unter einer µs, was mehr als tausend Mal schneller ist.

3

Die Integration ist eine berechnung, die die Fläche unter einer Funktion bzw. Signalverlauf beschreibt Botenstoffe die das Signal über die Synapse übertragen

Einfach gesagt, werden die Eingangssignale unterschiedlich gewichtet. Das bedeutet, sie werden mit einem Wert, der zuvor gelernt wurde, multipliziert, dann summiert und zum Schluss durch eine Aktivierungsfunktion ausgegeben. Diese Aktivierungsfunktion ist meistens nicht linear oder eine Schrittfunktion.

Wie beim biologischen Neuron, ist in der Informatik ein einzelnes Neuron ziemlich nutzlos, da sie ausser simple Aufgaben, wie die Funktion verschiedener logischer Operatoren, nichts können. Darum begann man, diese künstlichen Neuronen miteinander zu verknüpfen, wodurch künstliche neuronale Netzwerke entstanden sind. Mit der Hilfe dieser Netzwerke werden bis heute noch Künstliche Intelligenzen konstruiert, die Aufgaben, wie Bild-

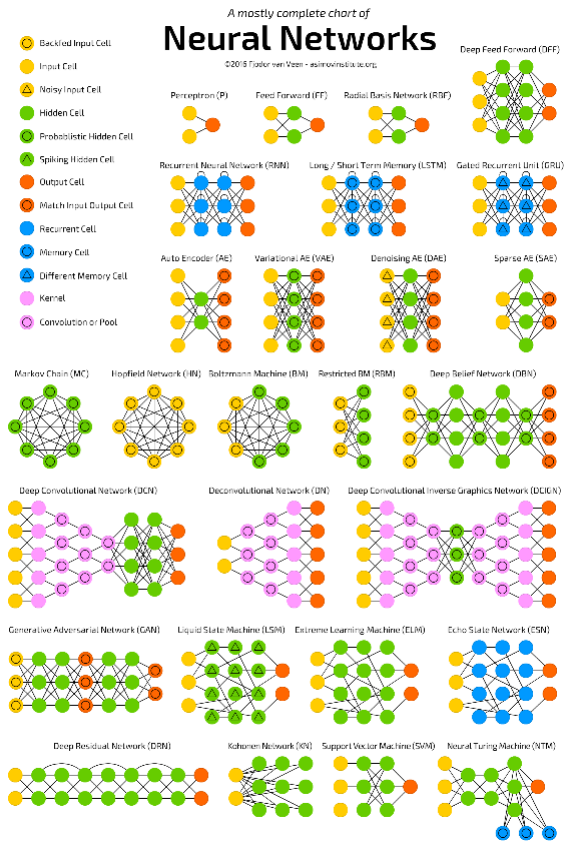
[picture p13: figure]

oder Spracherkennung, übernehmen können.

In Abb 3 werden alle bisher standardisierten neuronalen Netzwerke aufgelistet. Wobei die Punkte einem Neuron, und die Linien einer Verbindung zwischen zwei oder mehr Neuronen entsprechen.

An diesem Punkt kommt, eine für unsere BMA, wichtige Eigenschaft von künstlichen Neuronen ins Spiel.

Neuronale Netze werden auf einem Computer simuliert. Das bedeutet, dass der Signalverlauf durch das neuronale Netzwerk sequenziell und in der Taktung des Computers verläuft. Ein Computer kann immer nur eine Aufgabe zu einem Zeitpunkt erledigen und ist durch das, trotz der schnelleren Laufzeit, pro Neuron dem biologischen Neuron, welches alle Neuronen und Signale Simultan und in Echtzeit «Berechnen» kann, weit unterlegen.

C. Anforderungen an unser Modell
Es soll eine Schaltung erstellt werden, die Mathematischen Berechnungen eines Neurons imitiert. Dadurch kann eine lernende Schaltung entwickelt werden, die dynamische bzw. lernende Schaltkreise ermöglichen.

Als «lernen» ist zu verstehen, dass die Schaltung berechnet, wie sie welche Eingänge verarbeiten soll. Das passiert, indem der Nutzer am Eingang Daten anlegt und für eine

Abb 3: Chart of Neural Networks (Tch, 2017)

gewisse Trainingsphase, gleichzeitig einen Sollwert für den Ausgang definiert. Mit der Zeit lernt also die Schaltung, wie sie die Eingangsdaten verarbeiten soll und wie sie darauf reagieren soll. Nach der Trainingsphase soll die Schaltung selbständig neue Eingangsdaten interpretieren und einordnen.

Im Idealfall soll unser Neuron so schnell sein, wie das Neuron aus der Informatik, funktionieren und dennoch in Echtzeit und parallel die Berechnungen durchführen. Um die Schaltung einfach zu Skalieren⁵

und eine Abhängigkeit von Herstellern zu vermeiden, soll es nur aus einfachen elektronischen Komponenten, wie Transistoren, Widerstände, Dioden und Kondensatoren bestehen. Das bedeutet, dass keine Integrierte Schaltungen, auch ICs genannt, verwendet werden.

D. Überprüfung des Modells
Damit das Folgende auch gut verstanden werden kann, eine kurze Erklärung zu den Fachbegriffen. In der Elektronik bzw. Digitaltechnik wird mit dem binären Zahlensystem gearbeitet. Diese Zahlen werden aus Einsen und Nullen gebildet.

Jede 0 und 1 hat einen Zahlenwert, den sie repräsentiert. Im Binärsystem wird die Wertung von rechts nach links pro Stelle verdoppelt. D.h. die erste Ziffer von rechts steht für eins, die zweite für zwei, die dritte für 4 usw.. Steht eine Eins an der Stelle wird die entsprechende Wertung dazuaddiert, steht da eine Null, wird sie weggelassen.

Bsp.:
0001 entspricht im Dezimalsystem der Zahl 1.
0010 entspricht der Zahl 2.
0011 entspricht der Zahl 3.
0100 entspricht der Zahl 4.
Usw.

In der Praxis entspricht die 1 einer Spannung von 5 Volt (auch «High» genannt) und die 0 einer Spannung von 0V (auch «Low» genannt).

Um diese Informationen in der elementarsten Weise zu verarbeiten, werden drei Grundgatter verwendet:

AND:

Abb 4: UND Gatter (Stefan506, Wikipedia, 2005)

Um auch eine Verwendung als Integrierte Schaltung zu ermöglichen

Tabelle 1: Logiktabelle von einem UND Gatter

A | B | Y
0 | 0 | 0
0 | 1 | 0
1 | 0 | 0
1 | 1 | 1

Das AND-Gate verknüpft die Eingänge (A & B) so, dass der Ausgang (Y) nur einem «High» entspricht, wenn A und B zur gleichen Zeit auch «High» sind. Jede andere Kombination führt zu einem «Low» am Ausgang.

OR:

Abb 5: ODER Gatter (Stefan506, Wikipedia, 2005)

Tabelle 2: Logiktabelle von einem ODER Gatter

A | B | Y
0 | 0 | 0
0 | 1 | 1
1 | 0 | 1
1 | 1 | 1

Das OR-Gate verknüpft die Eingänge (A & B) so, dass der Ausgang (Y) einem «High» entspricht, wenn mindestens einer der beiden Eingänge «High» ist.

NOT:

Abb 6: NICHT Gatter (Stefan506, Wikipedia, 2005)

Tabelle 3: Logiktabelle eines NICHT Gatter

A | Y
0 | 1
1 | 0

Das NOT-Gate besitzt nur einen Eingang (A). Das Gatter macht nichts anderes, ausser dem Gegenteil vom Eingang auszugeben.

### 1. Testmöglichkeiten

Um zu überprüfen ob das Neuron auch lernt, soll es die Aufgabe von logischen Gattern (AND, OR) übernehmen bzw. lernen. Um zu überprüfen, ob das Neuron in der Lage ist, zu merken, wenn ein Eingang nicht benötigt wird, wird neben den notwendigen Eingängen auch noch ein überflüssiger Eingang benutzt, der Ignoriert werden soll. Wenn dies zuverlässig funktioniert, kann man davon ausgehen, dass das Neuron in der Lage ist bedingt komplexe⁶ Zusammenhänge zu approximieren und wichtige von nicht wichtiger Information zu unterscheiden.

### 2. Unmöglichkeiten

Da das Neuron auf keinen Fall in der Lage ist, Invertierungen (NOT-Gatter) zu imitieren, sind Kombinationen auf der Basis «Wenn ein Eingang nicht eingeschaltet ist, dann…» von Anfang an auszuschliessen und unmöglich für das Neuron zu erlernen.

Um es in technischer Sprache zu sagen, das Neuron ist nicht in der Lage XOR, XNOR, NAND, NOR oder NOT Gatter zu erlernen, da nach dem Aufbau des Eingangs (Inputs⁷

)
immer ein Stromzufluss herrschen muss.
E. Unser Modell
Aus den Anforderungen wird klar, dass wir kein Rechenzentrum in getakteter form haben können, sondern eine Schaltung benötigen die fliessend den Ausgang berechnen kann.

Bei dem Paper «Introduction to spiking neural networks» von (Ponulak & Kasinski, 2011) ist uns aufgefallen, dass in der Informatik eine Art von neuronalem Netzwerk existiert, das darauf ausgelegt ist, ein biologisches Neuron so gut wie möglich zu imitieren. In der Informatik konnte sich diese Art von neuronalem Netzwerk bisher noch nicht gut durchsetzen, weil es mehr Rechenleistung als ein Netzwerk einer anderen Art benötigt und schwer zu trainieren ist.

Die Funktion dieser Art Neuron ist identisch zu der Grundstruktur vom Informatischen Model, jedoch ist der Ausgabewert nicht analog, sondern in einer digitalen Form, nach dem «Alles oder Nichts»- oder dem Binärprinzip. Von diesem Prinzip hat diese Art Netzwerk ihren Namen «Spiking Neural Network», was auf Deutsch «Gepulstes Neuronales Netzwerk» bedeutet.

6

Darunter werden Zusammenhänge, die ein mehrschichtiges Neuronales Netz erfordern, verstanden. Die Schaltung wird im Kapitel VI.B Input auf der Seite 14 genauer erklärt.

Dieses gepulste Neuronale Netzwerk benötigt vor allem mehr Rechenleistung, weil es die elektronischen Vorgänge in einem Neuron simuliert. Das ist bei einem getaktetem Computer durchaus ein Problem, in der Elektronik jedoch nicht, da dort die Physik das Berechnen der Schaltung übernimmt.

Der Nachteil ist, es ist zeitabhängig. Was bedeutet, dass zeitlich alles gut aufeinander abgestimmt sein muss, was das Trainieren unheimlich erschwert.

A. Mathematischer Ansatz
In diesem Abschnitt wird die Berechnung der Schaltung vorgestellt und erklärt. Diese Formeln ermöglichen uns, zu erahnen welche Schaltungsteile wir benötigen und wie wir sie ungefähr verbinden Müssen. Sie zeigen auch auf, welche Funktionen erfüllt werden müssen. Es ist zu beachten, dass mit idealen Bauteilen gerechnet wird und keine Toleranzen von Bauteilen miteinbezogen sind, da diese nicht vorhersehbar sind.

### 1. Spannung am Kernkondensator

Aus diesem Paper «Introduction to spiking neural networks» von (Ponulak & Kasinski, 2011) konnten wir auch die Formel

Abb 7: «The Dynamics of the LIF unit» (Ponulak & Kasinski, 2011)
entnehmen, welche die Basis für die mathematische Beschreibung von unserem Modell ist. Aus der Formel von Abb 7: «The Dynamics of the LIF unit» (Ponulak & Kasinski, 2011) kann
man herauslesen, dass die Eingänge mit einem Werte multipliziert (Gewichtet) und i | w
summiert werden. Hinzu kommt der sogenannte Bias , welcher einen Grundladestrom der i0 konstant ist liefert. Von diesem Zuflussstrom wird ein Abflussstrom abgezogen, welcher von
der Spannung zum Zeitpunkt und dem Widerstand abhängig ist. Das ist ein u | t | R | C
Kondensator der als Integrierendes Element benutzt wird.

Damit wir diese Formel aus Abb 7 in einer Schaltung darstellen können, müssen wir jedoch einige Änderungen vornehmen. Das grösste Problem ist die Gewichtung , welche mit dem w Eingangsstrom multipliziert wird. Es ist in der Elektronik nur sehr schwer möglich, Spannungen mit einer Variabel zu Multiplizieren, zudem wird dies durch die Anforderung, dass nur Einfache Bauelemente benutzt werden, nahezu unmöglich für uns.

Unsere Lösung ist, dass wir die Eingangsspannung durch einen variablen Widerstand teilen, was zu einem variablen Strom führt. Ausserdem ist in der Formel aus Abb 7 keine Funktion für das Zurücksetzen der Kondensatorladung miteinbezogen. Da dieses Zurücksetzen für uns eine essentielle Komponente ist, müssen wir sie in unserer Formel mit einberechnen.

Formel 1: Berechnung der Kernkondensatorspannung

Uc
:Die spannung am Kernkondensator

C:Kapazität des Kernkondensators

R0:Entladungs Widerstand am Kernkondensator

n:Anzahl eingänge

Uxi

:Sapnnung Am eingang i

RTi

:Funktion des Transitor ― Widerstands in abhängikeit der Spannung UcTi

UcTi

: Spannung des Kondensators am Gate des Transitors

Ibias:Strom des Statischen 5V eingangs

Rdisc: Widerstand des Entladungstransitors

Wenn der Kern-Kondensator eine Gewisse Spannung (U erreicht, wird ein «Spike» ref) erzeugt, was am Ausgang ausgegeben wird. Dieser «Spike»⁸

wird durch eine
Aktivierungsfunktion erzeugt. Beim Generieren dieses «Spikes» wird der discharge-Transitor
durchgesteuert und der Widerstand | geht gegen Rdisc | 0Ω, was zu einer plötzlichen Entladung
des Kernkondensators führt.

### 2. Aktivierung

Y(t) =

d

dt({
0,Uc
(t) < Uref
1,Uc
(t) > Uref

∗ Vcc)

Formel 2: Funktion der Ausgabe

Uc
:Kernkondensator Spannung

Uref:Statische Referenz Spannung

Vcc:Speise Spannung des Prints

Eine kurze Spannungsspitze

C

dUc

(t)
dt = ―

Uc

(t)
R0

+ (∑
n
i

Ux
i

(t)

RTi

(UcTi

(t))) + Ibias(t) ―
Uc

(t)
Rdisc(Ua(t))

Y : Ausgabe der Schaltung

Sobald der Spike erzeugt wird, wird über den Discharge-Transitor auf 0V gezogen. Was Uc zur Folge hat, dass, wenn der Input dauerhaft auf 5V gestellt ist, sich ein «Spike Train» mit einer festen Frequenz bildet.

### 3. Fehlerberechnung

Damit das Neuron überhaupt etwas lernt, muss eine Art Feedback vom Nutzer oder von der Umgebung kommen. Dafür wird ein Rückgabewert ( ) verwendet. Mit diesem Rückgabewert S

kann die Gewichtung | angepasst werden, indem | verändert wird.

1

RTi

(UcTi

(t))

UcTi

dUcTi

(t)
dt =

1
V

2
cc ∗ RLR

∗ UXi

(t) ∗ |S(t) ― Y(t)| ∗ (|S(t) ― Y(t)| ― UcTi

)

Formel 3: Berechnung des Fehlers

UcTi

: Spannung des Kondensators am Gate des Transitors

CT : Kondensator am Gate des Transistors i

: Spannung am Eingang Uxi
i

RLR : Widerstand, der die Ent-/Lade Geschwindigkeit des Kondensators angibt (Lern- CTi Schrittgeschwindigkeit)

Vcc:Speise Spannung des Prints

S: Ziel Spike-Train, dass das Neuron erreichen soll

Da und zeitbegrenzte Pulse sind, wird der Kondensator nur ein klein wenig S Y entladen/geladen was den Transistor am jeweiligen Eingang etwas mehr sperren oder leiten
lässt. Dadurch können alle Inputgewichte über die Zeit so eingestellt werden, dass | dem S(t)
Ausgang | entspricht. Y(t)

Dies ist natürlich nur bis zu einer gewissen Komplexität möglich. Vor allem, da die Eingangsströme nicht negativ sein können.

B. Problematik von Theorie und Praxis
Die grösste Problematik ist, dass das Speichern von analogen Spannungen nur sehr schlecht geht und sehr störungsanfällig ist. Man kann die Schaltung etwas stabilisieren, indem man den Print so gut wie möglich isoliert, um jeglichen Energieverlust über benachbarte Leitungen zu vermeiden.
C. Bedingungen/Einschränkungen
Es gibt gewisse Probleme bei der Übersetzung vom Modell in die reale Welt. Zum Einen ist die Praxis nie perfekt, Bauteile haben Toleranzen, Unendlichkeiten gibt es nicht und es ist nicht möglich, Spannungen auf eine einfache Art und Weise zu multiplizieren. Hinzu kommt, dass die gewünschte Formel auch nicht in reiner Form vorkommen wird.

Um die Schaltung kleiner, bzw. in einer sinnvollen Grösse, zu behalten, verzichten wir auf negative Eingangsströme, was die Diversität an lernbaren Funktionen einschränkt, aber keinen Einfluss auf die Funktion der Schaltung hat.

D. Blockschaltbild

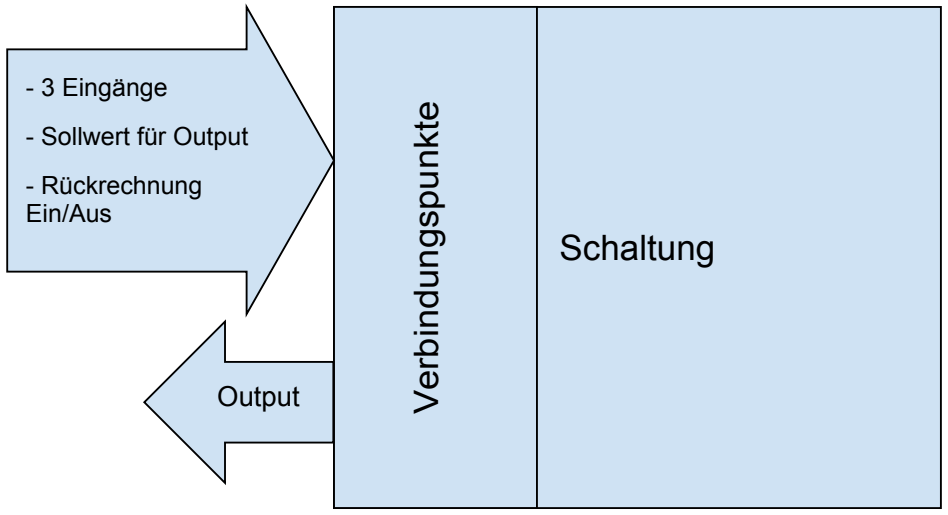
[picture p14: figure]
Schaltung; Verbindungspunkte; - 3 Eingänge; - Sollwert für Output; - Rückrechnung Ein/Aus; Output

Abb 8: Blockartige Übersicht der Schaltung
In der obigen Abbildung (Abb 8) wird die minimalste Grundstruktur des gesamten Systems dargestellt. Die gesamte Peripherie der Schaltung besteht aus sechs Verbindungspunkten. Drei Eingänge, welche die Signale in die Schaltung führen. Einen Eingang für den Sollwert, welcher die Schaltung in der Trainingsphase benötigt, um zu lernen. Der Eingang für die Rückrechnung Ein/Aus ist dafür da, um der Schaltung zu sagen ob sie sich in der Trainingsphase oder im Normalbetrieb befindet. Der Output ist die Ausgabe der Schaltung für einen gegebenen Eingangszustand an den drei Eingängen. Die Ausgabe der Schaltung ist immer vorhanden, auch wenn sie sich in der Trainingsphase befindet.

## VI. Praxis

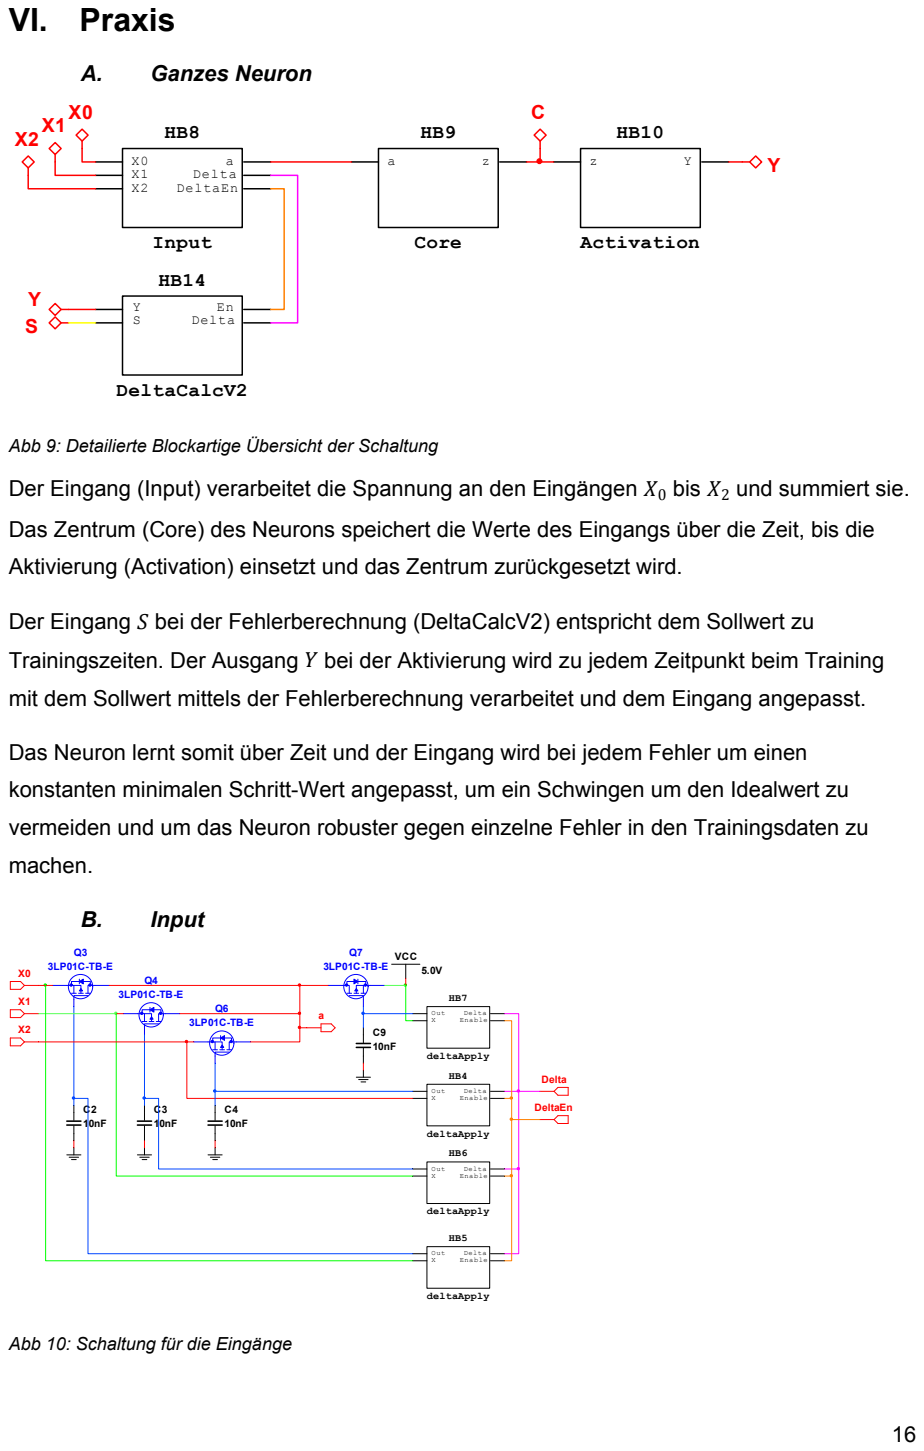
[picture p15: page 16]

Abb 9: Detailierte Blockartige Übersicht der Schaltung
Das Zentrum (Core) des Neurons speichert die Werte des Eingangs über die Zeit, bis die
Aktivierung (Activation) einsetzt und das Zentrum zurückgesetzt wird.

Der Eingang bei der Fehlerberechnung (DeltaCalcV2) entspricht dem Sollwert zu S
Trainingszeiten. Der Ausgang bei der Aktivierung wird zu jedem Zeitpunkt beim Training Y
mit dem Sollwert mittels der Fehlerberechnung verarbeitet und dem Eingang angepasst.

Das Neuron lernt somit über Zeit und der Eingang wird bei jedem Fehler um einen
konstanten minimalen Schritt-Wert angepasst, um ein Schwingen um den Idealwert zu
vermeiden und um das Neuron robuster gegen einzelne Fehler in den Trainingsdaten zu
machen.

Abb 10: Schaltung für die Eingänge

Die Eingangsspannungen | bis | werden über die, zum Teil leitenden, Transistoren in X0 | X2
spezifische Ströme umgewandelt und am Ausgang summiert.

Die Spannungen an den Kondensatoren bestimmen, wie stark die Transistoren durchsteuern. So kann der Widerstand der Transistoren kontrolliert werden. Die Spannung an den Kondensatoren wird über die Fehlerberechnung verändert.

Im mathematischen Sinne entspricht diese Teilschaltung dem Abschnitt
(∑
n
i

Ux
i

(t)

RTi

(UcTi

(t))) + Ibias(t)

Aus der Formel für die Vorwärtsrechnung.

Der | kommt von dem Transistor , der direkt an | angeschlossen ist. Ibias(t) | Q7 | Vcc

### 1. DeltaApply

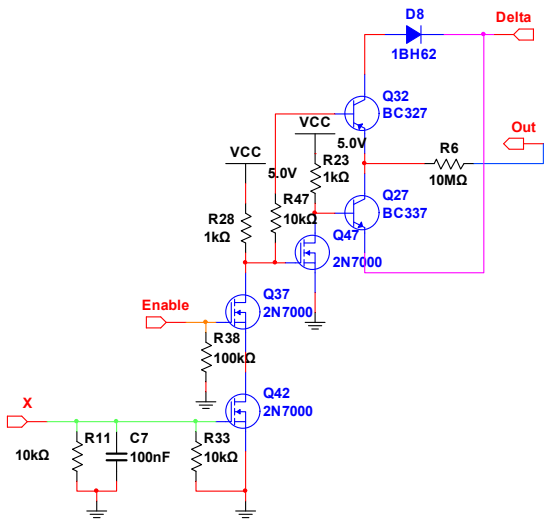
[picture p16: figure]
Delta; Enable; Out; Q32 BC327 VCC; VCC

Abb 11: Schaltung für das Anpassen der Kondensatorspannung
Diese Teilschaltung ist für das Anpassen der Spannungen am Kondensator zuständig. Jeder Eingang besitzt eine solche Teilschaltung. Der Eingang Delta bestimmt, ob der Core-Kondensator geladen oder entladen wird. Enable schaltet mit der Spannung am Transistor den Rückrechnungsvorgang ein oder aus. Der Eingang sagt der Schaltung, ob der X Eingang der Gesamtschaltung überhaupt aktiv war.
Diese Teilschaltung ist die Umsetzung des Formelabschnittes | ,

1
V

2
cc ∗ RLR

∗ UXi

(t) ∗ E ∗ (D ― UcTi

)

wobei dem Enable Eingang, | dem Eingang und dem Delta Eingang entspricht. E | UXi | X | D
C. Core

R14
1kΩ

C16
10nF
a | z

Abb 12: Schaltung des Kerns
Der Core besteht hauptsächlich aus einem Kondensator , welcher über den Eingang C | a
aufgeladen wird. Für den Fall, dass keine Signale über die Eingänge | bis | kommen, X0 | X2
sorgt der Widerstand dafür, dass sich der Kondensator langsam entlädt und nach einer R gewissen Zeit der Kondensator wieder zurückgesetzt ist.
Die mathematische Darstellung der Teilschaltung ist | . Dabei entspricht C

dUc

(t)
dt = ―

Uc

(t)
R0
+a | a
dem Ausgang der Input-Teilschaltung.
D. Activation

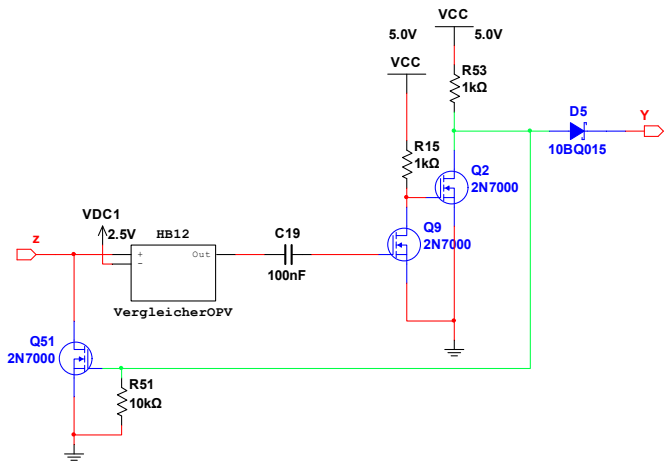
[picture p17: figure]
VDC1; VCC; VergleicherOPV; Out

Abb 13: Aktivierungsschaltug
Die Aktivierung ist dazu da, um zu bestimmen, ob ein Signal weiter- bzw. ausgegeben werden soll. Wenn die Spannung am Core(Kondensator) über die 2.5V steigt, schaltet der Vergleicher von 0V auf 5V über eine sehr kurze Zeit. Durch diese rapide Änderung gibt es eine Spannungsspitze auf der anderen Seite des Kondensators. Diese Spannungsspitze wird über die zwei folgenden Transistoren verstärkt, damit das Ausgangssignal eine höhere Spannung erreicht und auch mehr Strom liefern kann.

Dieses Ausgangssignal wird über die grüne Leiterbahn zurückgeführt und entlädt das Core (Kondensator) sehr schnell, wodurch dieser wieder unter die 2.5V fällt und der Ausgang des Vergleichers wieder auf 0V schaltet. Danach beginnt der Vorgang von vorne.

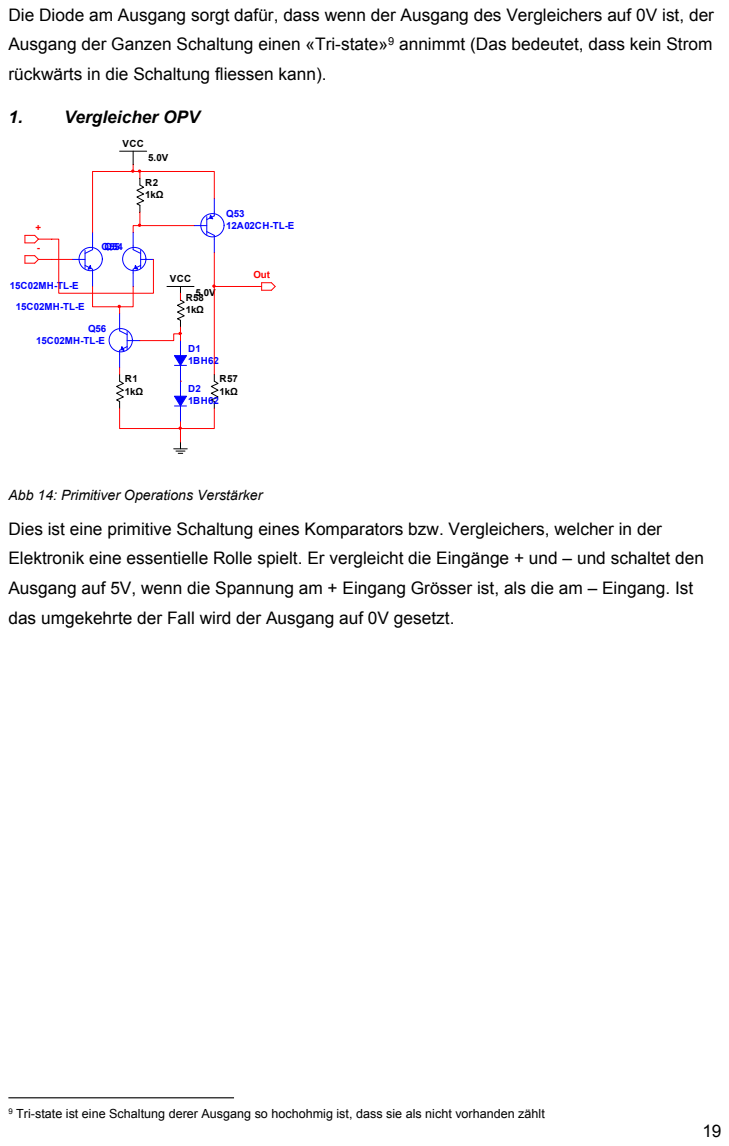
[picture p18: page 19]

Die Diode am Ausgang sorgt dafür, dass wenn der Ausgang des Vergleichers auf 0V ist, der
Ausgang der Ganzen Schaltung einen «Tri-state»⁹
rückwärts in die Schaltung fliessen kann).

annimmt (Das bedeutet, dass kein Strom

Abb 14: Primitiver Operations Verstärker
Dies ist eine primitive Schaltung eines Komparators bzw. Vergleichers, welcher in der
Elektronik eine essentielle Rolle spielt. Er vergleicht die Eingänge + und – und schaltet den
Ausgang auf 5V, wenn die Spannung am + Eingang Grösser ist, als die am – Eingang. Ist
das umgekehrte der Fall wird der Ausgang auf 0V gesetzt.

Tri-state ist eine Schaltung derer Ausgang so hochohmig ist, dass sie als nicht vorhanden zählt

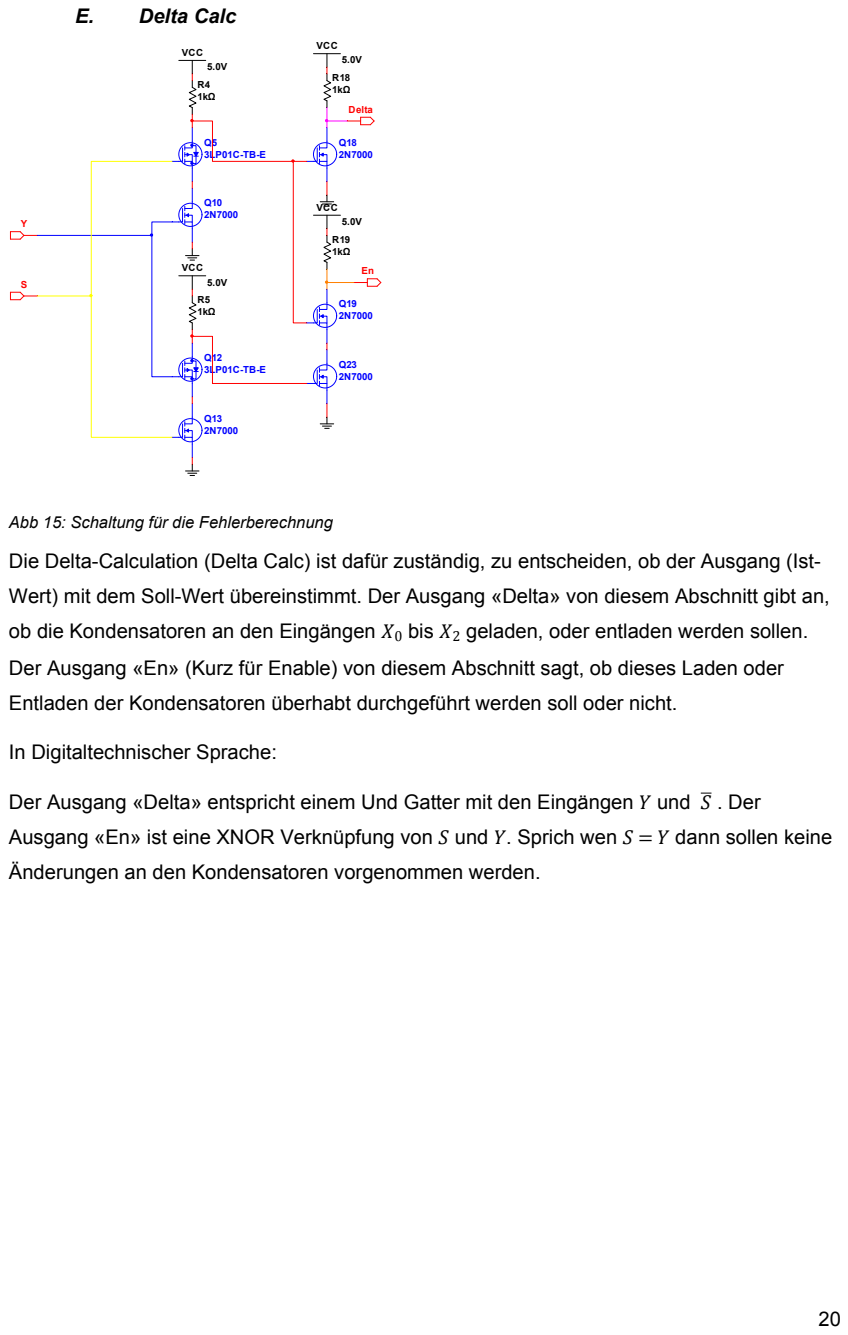
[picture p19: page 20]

Abb 15: Schaltung für die Fehlerberechnung
Die Delta-Calculation (Delta Calc) ist dafür zuständig, zu entscheiden, ob der Ausgang (Ist-
Wert) mit dem Soll-Wert übereinstimmt. Der Ausgang «Delta» von diesem Abschnitt gibt an,
Der Ausgang «En» (Kurz für Enable) von diesem Abschnitt sagt, ob dieses Laden oder
Entladen der Kondensatoren überhabt durchgeführt werden soll oder nicht.

Änderungen an den Kondensatoren vorgenommen werden.

## VII. Messungen

A. Messung des Eingangs
Um zu überprüfen ob der eingangs Stroms mit den Transistoren kontrolliert werden kann, haben wir eine Eingangs-Teilschaltung (Input) mit einem Kernstück mit dem Fräsbohrplotter erstellt. Es wurden wären der Messung zwei separate Spannungsquellen verwendet. Um die Spannungspotenziale aufeinander abzustimmen, wurde von allen Speisungen den Nullpunkt¹⁰ zusammengeschaltet. Eine Speisung wurde als die Eingangsspannung verwendet mit einem konstanten 5V Pegel. Die Zweite, wurde für die direkte Kontrolle über die Spannung des Kondensators¹¹ , an den Kondensator direkt angelegt. Nach unserem UCT Model sollte somit der Strom durch den Transistor mit der Spannung an dem Kondensator beeinflussbar sein.
UC Eingang (in V) T | UC Kern (in V) | I Eingang (in mA)
4,0 | 0,000 | 0,01
3,9 | 0,000 | 0,01
3,8 | 0,000 | 0,01
3,7 | 0,031 | 0,01
3,6 | 0,154 | 0,03
3,5 | 0,584 | 0,08
3,4 | 1,019 | 0,30
3,3 | 1,948 | 0,93
3,2 | 3,654 | 2,67
3,1 | 3,967 | 2,97
3,0 | 4,911 | 3,82
2,9 | 4,939 | 3,84
Tabelle 4: Messergebnisse über den Eingansstrom
Aus der Tabelle 4 lässt sich herauslesen, das dies uns Erfolgreich gelungen ist. Es wird auch
gut ersichtlich, dass der Strom Exponentiell ansteigt mit sinkender Spannung an | . Die UCT
Spannung an | zeigt die Spannung im Equilibrium, das ist der Punkt an dem UC | Iein
B. Messung der Aktivierung
Bei der Aktivierung (Activation) handelt es sich um eine Schaltung die, wenn der Referenzpunkt überschritten wird, einen Spike ausgibt. Wenn der Eingangsstrom Uref konstant ist, fängt die Schaltung an, zu schwingen. Dies bedeutet, wenn eine Konstante DC Spannung angelegt wird, wird bei der Ausgabe ein Spiketrain¹² entstehen.

10 Die Spannuung die 0 Volt entspricht
11 Kondensator der sich unten an dem Transistor bei den Eingängen befindet. 12 Eine Abfolge von einzelnen Spikes

Um dies zu messen, haben wir eine Teilschaltung dieser Aktivierung mit dem Fräsbohrplotter
erstellt. Mit einem Eingang für die DC-Eingangsspannung und einem Ausgang als Z | Y
Messpunkt für das Ausgangssignal.

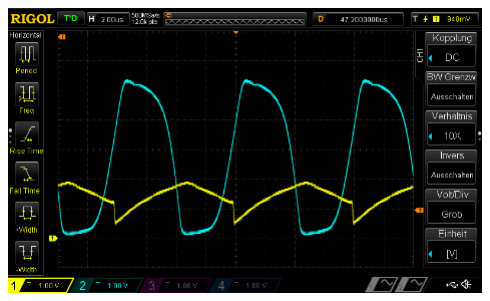
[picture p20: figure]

| In der nebenstehenden Abbildung (Abb 16) ist das Ergebnis der Messung ersichtlich. Es ist sichtbar, dass die Eingangsspannung (der blaue Graph) immer einbricht, wenn die Schaltung einen Spike erzeugt. Diese Spikes (der gelbe Graph) haben jedoch einen etwas zu tiefen Höhepunkt. Daraus lässt sich schliessen, dass die

Ausgangsspannung zu wenig verstärkt wird.

In der Messung der Spikes (Abb 17), wo nur die Spikes an sich gemessen und ins Verhältnis gesetzt wurden, sieht man jedoch, dass schöne Spikes entstehen, die mit einer Frequenz von ca. 100kHz auftauchen, was nach Anforderungen von unserem Modell in einem akzeptablen

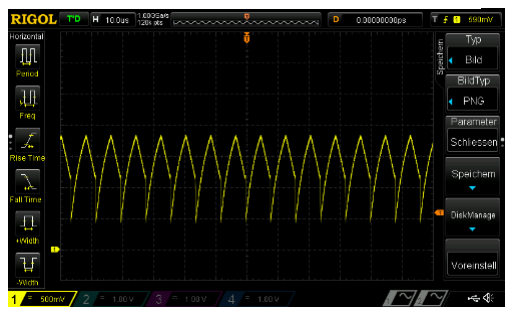
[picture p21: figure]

Bereich liegt. Dies könnte jedoch verbessert werden in dem man die einzelnen Bauteile etwas anpasst.

C. Messung der Delta Calculation
Wir wollten diese Teilschaltung auch verifizieren. Jedoch konnten wir diese Messung nicht durchführen, da ein Fehler beim Fräsbohrplotter aufgetaucht ist, welche zu einem Kurzschluss auf der Platine führte. Wir konnten den Fehler auch nach einigen Stunden nicht finden und mussten aufgrund des Zeitdrucks diese Messung überspringen. Wir konnten uns dies Erlauben, da diese Teilschaltung eine logische Schaltung ist und nach Vorgaben der Digitaltechnik funktionieren muss und in unserer Schaltung nicht als kritisches Element gilt.
D. Messung von DeltaApply
Diese Teilschaltung war für uns eine heiklere Schaltung, weil sie nur schlecht gemessen werden kann, ohne die Schaltung zu beeinflussen. Auch von dieser Schaltung wurde eine Teilschaltung mit dem Fräsbohrplotter erstellt und ausgemessen.

Abb 16: Messung der Activation Digital Oszi. (DC)

Abb 17: Messung der Spikes

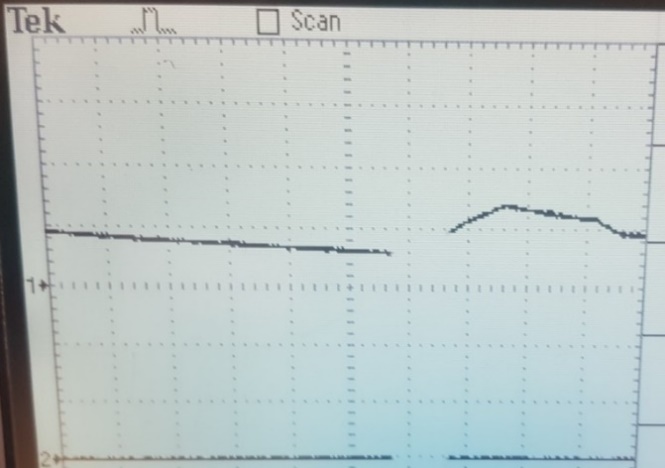
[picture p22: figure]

Abb 18: Messung von DeltaApply
Die obige Abbildung (Abb 18) zeigt den Verlauf der Kondensatorspannung, der mittels der DeltaApply Schaltung geladen und Entladen wurde. Die erste Strecke zeigt, wie der Kondensator kontrolliert entladen werden konnte. Der von links nach rechts Steigende Abschnitt zeigt ein Ladevorgang. Am obigen Wendepunkt der Spannungskurve, wurde der Kondensator weder geladen, noch Entladen. Es ist jedoch trotzdem eine kleine Entladung zu sehen, weil die Spannung abfällt. Dies passiert zu einem Anteil, weil der Kondensator sich über das Messgerät entladen kann, was das Ergebnis etwas verfälscht. Zum anderen ist der Kondensator nicht perfekt isoliert und kann sich über die Umgebungsluft Richtung Erde entladen. Dies hatten wir jedoch erwartet, zumal diese Teilschaltungsplatine von schlechter Qualität war und viele Möglichkeiten zum entladen anbot.

## VIII. Fazit

Im Grunde sind die Messungen der Teilschaltungen positiv ausgefallen. Man kann aber wegen der nicht funktionierenden Gesamtschaltung keine eindeutigen Schlüsse ziehen.

Wir schafften es schlussendlich nicht, eine funktionierende Endversion unseres Prints zu produzieren. Das hat mehrere Gründe. Zum einen hätten wir uns grundsätzlich mehr Zeit einrechnen müssen für die Phase des Aufbaus und der Inbetriebnahme der Schaltung. Zum anderen ist unsere Printbestellung nicht wie geplant eingetroffen, was für uns massiv mehr Arbeit bedeutete, da wir die Endversion schlussendlich selbst ausfräsen mussten und unsere Fräsmaschine einige Teile der Schaltung sehr Störungsanfällig konstruierte. Obwohl wir das gesamte Wochenende vor der BMA-Abgabe an dem Print gearbeitet haben, reichte die Zeit am Ende doch nicht. Mit einer Woche mehr Zeit, wäre all dies zu vermeiden gewesen. Dann hätten wir nämlich den «qualitativ hochwertigen» Print aus dem Ausland in Betrieb nehmen können.

Dies werden wir aus Interesse trotzdem noch tun. Ausserdem, sind wir davon überzeugt, dass man unsere Fragestellung, ob die Realisierung eines Neurons, in Form einer elektrischen Schaltung, möglich ist mit Ja beantworten kann. Grund dafür ist, dass bis auf die

Teilschaltung «delta Calc» alle bereits funktioniert haben, wie sie im Kapitel Messungen gesehen haben. Das «delta Calc» ist aber im Grunde nur eine Logikschaltung und man kann davon ausgehen, dass diese auch funktionieren würde.

Um unsere Schaltung vor dem Aufbau auszutesten, benutzten wir ein Simulationstool, namens Multisim. Mit diesem konnten wir unsere Theorien und Berechnungen überprüfen. In dieser Simulation funktionierte unsere Schaltung. Ein weiteres Indiz dafür, dass unsere Schaltung theoretisch hätte funktionieren können.

Wie in der Einleitung erwähnt, wollten wir unsere Fragestellung mit einem funktionierenden Endprodukt beantworten. Wegen der fehlenden Zeit, sehen wir aber das nichtfonktionieren der Schaltung nicht als repräsentativ an. Wir beantworten stattdessen die Fragestellung, aufgrund der beiden oben genannten Argumente, mit Ja.

Wir haben gelernt, dass es wichtig ist, bei einer Arbeit solchen Ausmasses früher anzufangen Prototypen zu realisieren. Die digitale Version im Simulationstool reicht natürlich nicht. Wir haben leider erst 3 Wochen vor der Abgabe angefangen, am ersten physischen Prototypen zu arbeiten.

Weiterführend könnte man sich die Frage stellen, ob mit mehreren solchen Neuronen ein selbstlernendes Netzwerk erstellt werden kann, indem man Ein und Ausgänge zusammenhängt. Unser Hirn ist ja im Prinzip auch nur ein Haufen zusammengeschalteter Neuronen. Diese Fragen finden wir so interessant, dass wir uns vermutlich weiter damit befassen werden, nach der BMA.

## IX. Formelverzeichnis

## X. Abkürzungsverzeichnis

usw. = und so weiter

bzw. = beziehungsweise

DC = direct current / Gleichspannung

KO = Oszilloskop

d.h. = das heisst

## XI. Abbildungsverzeichnis

## XII. Literaturverzeichnis

Ponulak, F., & Kasinski, A. (1. Januar 2011). Von https://www.ane.pl/cookie?page=linkout.php?pii=7146 abgerufen

Stefan506. (14. Dezember 2005). Wikipedia. Von https://de.m.wikipedia.org/wiki/Datei:Logic-gate-or-us.png abgerufen

Stefan506. (14. Dezember 2005). Wikipedia. Von https://de.wikipedia.org/wiki/Datei:Logic-gate-inv-iec.png abgerufen

Stefan506. (14. Dezember 2005). Wikipedia. Von https://de.wikipedia.org/wiki/Datei:Logic-gate-and-us.png abgerufen

Tch, A. (4. August 2017). towardsdatascience.com. Von https://towardsdatascience.com/the-mostly-complete-chart-of-neural-networks-explained-3fb6f2367464 abgerufen

Wikipedia. (3. Januar 2020). Wikipedia/Neuron. Von https://de.wikipedia.org/w/index.php?title=Nervenzelle&oldid=195474238 abgerufen

## XIII. Anhang

A. Layout/Bestückungsplan von EAGLE
B. Schema von EAGLE
C. Stückliste

## XIV. Deklaration

Hiermit erklären wir, dass wir die vorliegende interdisziplinäre Arbeit selbstständig und in eigener Sprache verfasst und keine anderen als die angegebenen Hilfsmittel verwendet haben. Wörtliche und sinngemässe Übernahmen aus anderen Quellen wie Büchern, Zeitschriften, Internet, Interviews usw. sind als solche kenntlich gemacht.

Ort: |
Datum: |
Unterschrift: |
Unterschrift: |

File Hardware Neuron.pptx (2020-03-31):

## Hardware Neuroon

Von Malik Schneider und Tendai Rondof

## Inhalt

- Fragestellung
- Vorgehensweise
- das Endprodukt
- Fazit

## Fragestellung

- Was ist eine Möglichkeit, ein Neuron (Nervenzelle) mittels Elektronischen teilen zu realisieren und kann damit eine selbstlernende, elektrische Schaltung (“Neuron”) erstellt werden?

## Vorgehensweise

- Informationsbeschaffung zu den verschiedenen Modellen
- Abgleichen der Modelle mit unseren Anforderungen
- Entscheidung für das Spiking Neural Network
- Formel für Modell umwandeln in Schaltung
- Simulieren und Design für Print erstellen

## Das Endprodukt

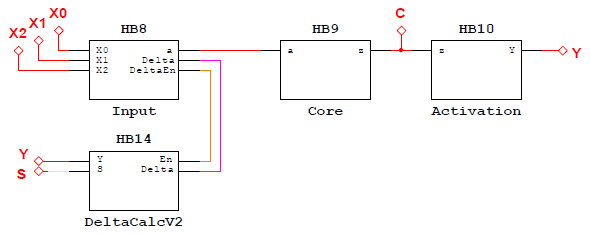
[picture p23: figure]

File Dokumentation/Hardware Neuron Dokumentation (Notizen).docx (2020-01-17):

# Hardware Neuron

Einleitung

was ist es?

was macht es?

was bringt es?

# Blockschaltbild des gesamten

Test Daten

Schaltung

Ausgabe

## Beispiel Komponente

wofür ist sie zuständig:

verweise auf andere stellen im Dokument:

Theorie

# Grundlage der Problematik

was soll erreicht werden:

Es soll eine Schaltung erstellt werden, die Mathematischen Berechnungen eines Perceptron imitiert. Dadurch kann eine lernende Schaltung entwickelt werden die Dynamische bzw. lernende Schaltkreise ermöglichen. Zudem wird die Rechenzeit für ein Perceptron reduziert.

Bedingungen/Einschränkungen:

Es gibt gewisse Probleme bei der Übersetzung vom Model in die reale Welt. Zum einen ist die Praxis nie perfekt. Bauteile haben Toleranzen, Unendlichkeiten gibt es nicht und es ist nicht möglich Spannungen auf eine einfache Art und Weise zu multiplizieren.

Die gewünschden Formel wird auch nicht in einer reinen Form vorkommen.

# Ansatz

Typ des Perceptrons (Vorteile gegenüber anderen Methoden)

Als Grundprinzip benutzen wir das Model eines Spicking-Preceprons, was ein einzelnes Neuron mit einem pulsierenden, digitalen Ausgang darstellt.

Der Vorteil gegenüber anderen Methoden ist, es kommt der Biologie am nächsten und die Rückberechnung ist mit einzelnen Transistoren machbar.

Der Nachteil ist, es ist zeitabhängig. Was bedeutet, dass zeitlich alles gut aufeinander abgestimmt sein muss.

Mathematischer Ansatz

Die Grundformen für den Kern des Neurons ist:

C(dU_c (t))/(dt)=-(U_c (t))/(R_0)+(∑_i^n (U_(x_i) (t))/(R_(T_i) (U_(c_(T_i)) (t))))+(I_(bias) (t))

U_c :Die spannung am Kern Kondensator

C:Kapazität des Kern kondensators

R_0 :Entladungs Widerstand am Kernkondensator

n:Anzahl eingänge

U_(x_i) :Sapnnung Am eingang i

R_(T_i) :Funktion des Transitor-Widerstands in abhängikeit der Spannung U_(c_(T_i))

U_(c_(T_i)) : Spannung des Kondensators am Gate des Transitors

I_(bias) :Strom des Statischen 5V eingangs

Problematik von Theorie und Praxis

Adaption von der Theorie zur Machbarkeit

Neue Bedingungen und Nachteile

# Schema Blockschaltbild

Schaltung

3 Eingänge

Stecker

Sollwert für Output

Output

## Beispiel Komponente

Funktionsweis

Gleichung

Abweichung Theorie Praxis

Hardware

# Schema

## Ganzes Neuron

Der Eingang (Input) verarbeitet die Spannung an den Eingängen X_0 bis X_2 und summiert sie. Das Zentrum (Core) des Neurons speichert die Werte des Eingangs über die Zeit bis die Aktivierung (Activation) einsetzt und das Zentrum zurückgesetzt wird.

Der Eingang S bei der Fehlerberechnung (DeltaCalcV2) entspricht dem Sollwert zu Trainingszeiten. Der Ausgang Y bei der Aktivierung wird zu jedem Zeitpunkt beim Training mit dem Sollwert mittels der Fehlerberechnung verarbeitet und Der Eingang angepasst.

Das Neuron lernt somit über Zeit und der Eingang wird bei jedem Fehler um einen konstanten minimalen Schritt-Wert angepasst um ein Schwingen um den Idealwert zu vermeiden und um das Neuron robuster gegen einzelne Fehler in den Trainingsdaten zu machen.

## Beispiel von Trainingsdaten

### X_0 :

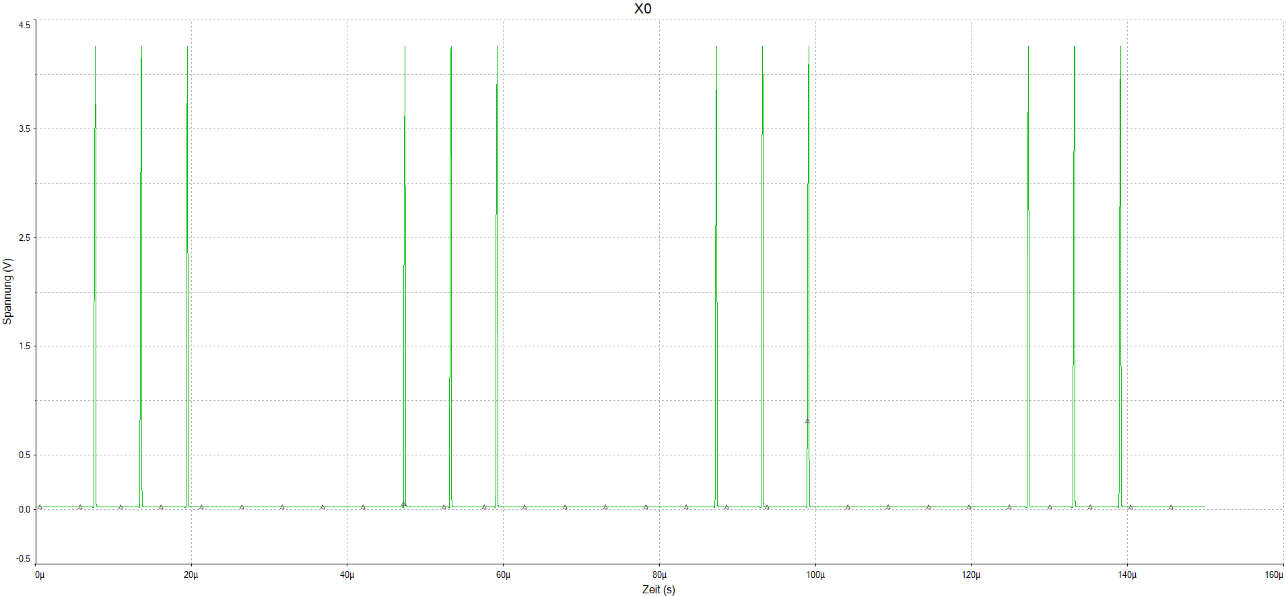
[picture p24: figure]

### X_1 :


### X_2 :


### S :


## Input

Die Eingangsspannungen X_0 bis X_2 werden über die, zum Teil leitenden, Transistoren in spezifische Ströme umgewandelt und am Ausgang summiert.

Die Spannungen an den Kondensatoren Bestimmen wie stark die Transistoren durchsteuern. So kann der Widerstand der Transistoren kontrolliert werden. Die Spannung an den Kondensatoren wird über die Fehlerberechnung verändert.

### DeltaApply

Dieser Teilschaltung ist für das anpassen der Spannungen am Kondensator zuständig. Jeder Eingang besitzt eine solche Teilschaltung. Der Eingang Delta bestimmt ob der Kondensator geladen oder entladen wird, Enable steuert mit der Spannung am

## Core

Das Core besteht hauptsächlich aus einem Kondensator C_16 welcher über den Eingang a aufgeladen wird. Für den Fall, dass keine Signale über die Eingänge X_0 bis X_2 kommen, sorgt der Widerstand R_14 dafür, dass sich der Kondensator langsam entlädt und nach einer gewissen Zeit der Kondensator wieder zurückgesetzt ist.

## Activation

### Vergleicher OPV

## DeltaCalc

## Verbindung Blockschaltbild Schema

# Layout/Bestückungsplan

# Messungen

Benutzeranleitung Anleitung

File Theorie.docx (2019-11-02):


x1

x2

x3

x1

x2

x3

x1+x2+x3-ruhepot > t = ausgang

w2

w1

w3

x1*w1+x2*w2… = x

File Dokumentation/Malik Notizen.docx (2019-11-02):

Biologische Version:


Potentiale(binär) häufen sich(Analog). sobald Threshhold überschritten wird, wird Aktionspotential ausgelöst und steuern Hormonfluss. Problem: negative Potentiale von synapsen. auch aktionspotentiale können negativ sein.

(Widerspricht binärem Prinzip weil Trinär)

Mathematische Version:


Analoge Potenziale multipliziert mit Gewichtung (z.B. von Memristor) ergeben aktionspotential. keinen Schwellenwert. kein Ruhepotential. je nach Formel zwischen 0 und 1 oder -1 und 1.


Rückrechnung

Wichtigste Aspekte:

Aktivierungsfunktion f(x)=1/(1+e^(-x)) (reicht von 0-1) abhängig von x=input

Errorfunktion E(y^(') ,Y)=1/2(Y-y')^2 Unterschied zwischen sollout und istout (quadriert und halbiert)

Delta w ∆w_i =(∂E(y^(') ,Y))/(∂w_i) (Ableitung von error nach w=-x)

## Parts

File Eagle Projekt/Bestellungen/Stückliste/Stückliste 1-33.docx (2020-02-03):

Produkt | | | | | | Nummer | | Index | Mikro | Blatt/Total
Baugruppe | | | | | | Stück | | Termin | | Auftrag
Erstellt | | Geändert | | | | Felder leer lassen, wird durch PPS ausgefüllt.
Geprüft | | Geprüft
Stk. | Gegenstand/Wert Zchng.Nr. | | Pos.Nr. | Zeile | Bestell-Nr./Material Lieferant | | | | | | C
1 | Print | | | 1 | JLCPCB | | | | | | BT
| | | | 2
4 | Widerstand/0805/1%/0.125W/10ME | | R7, R8, R22, R36 | 3 | MSW | | | | | | NT
37 | Widerstand/0805/5%/0.125W/1kE | | R1 … R6, R9 … R17, R19 … R21, R24 … R35, R37, R39 … R44, | 4 | MSW | | | | | | NT
3 | Widerstand/0805/5%/0.125W/10kE | | R18, R23, R38 | 5 | MSW | | | | | | NT
| | | | 6
6 | Kondensator/0805/50VDC/10nF | | C1 … C4, C7, C11 | 7 | 300-31-703 Distrelec | | | | | | BT
4 | Kondensator/0805/50VDC/100nF | | C5, C6, C9, C8 | 8 | 165-72-419 Distrelec | | | | | | BT
1 | Kondensator/0805/10 VDC/10uF | | C10 | 9 | 300-31-721 Distrelec | | | | | | BT
| | | | 10
2 | Gleichrichterdiode SOD-80 100 V (https://www.distrelec.ch/de/rectifier-diode-sod-80-100-diotec-egl1b/p/17003546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) | | D6, D7 | 11 | 301-46-784 Distrelec | | | | | | BT
5 | Shottky-Diode/0.12A/40 V/SOD-323 | | D1 … D5 | 12 | 300-57-642 Distrelec | | | | | | BT
| | | | 13
7 | Kleinleistungstransistor BC817/SOT-23/NPN/45V | | T1 … T8 | 14 | 300-32-500 Distrelec | | | | | | BT
5 | Kleinleistungstransistor BC807/SOT-23/PNP/45V | | Q2, Q3, Q15, Q22, Q23 | 15 | 171-30-354 Distrelec | | | | | | BT
20 | MOSFET N, 25 V 0.22 A 350 mW SOT-23 (https://www.distrelec.ch/de/mosfet-25-22-350-mw-sot-23-fairchild-fdv301n/p/17109648) | | Q6 … Q12, Q14, Q16 … Q21, Q24 … Q32 | 16 | 171-09-648 Distrelec | | | | | | BT
6 | MOSFET P, 50 V 225 mW SOT-23 (https://www.distrelec.ch/de/mosfet-50-225-mw-sot-23-on-semiconductor-bss84lt1g/p/30050365) | | Q1, Q4, Q5, Q13 | 17 | 300-50-365 Distrelec Distrelec | | | | | | BT
| | | | 18
1 | Wannenstecker N2510-6002R | | SV1 | 19 | MSW | | | | | | NT
| | | | 20
| | | | 21
| | | | 22
| | | | 23
| | | | 24
| | | | 25
| | | | 26
| | | | 27
| | | | 28
| | | | 29
| | | | 30
| | | | 31
| | | | 32
| | | | 33
*=Preis anfragen Stückliste.doc | | | EF=Eigenfabrikat BT=Bestellteil PA=Physikartikel NT=Normteil RM=Rohmaterial

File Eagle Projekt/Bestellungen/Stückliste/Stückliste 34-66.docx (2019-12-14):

Produkt | | | | | | Nummer | | Index | Mikro | Blatt/Total
Baugruppe | | | | | | Stück | | Termin | | Auftrag
Erstellt | | Geändert | | | | Felder leer lassen, wird durch PPS ausgefüllt.
Geprüft | | Geprüft
Stk. | Gegenstand/Wert Zchng.Nr. | | Pos.Nr. | Zeile | Bestell-Nr./Material Lieferant | | | | | | C
| | | | 34
| | | | 35
| | | | 36
| | | | 37
| | | | 38
| | | | 39
| | | | 40
| | | | 41
| | | | 42
| | | | 43
| | | | 44
| | | | 45
| | | | 46
| | | | 47
| | | | 48
| | | | 49
| | | | 50
| | | | 51
| | | | 52
| | | | 53
| | | | 54
| | | | 55
| | | | 56
| | | | 57
| | | | 58
| | | | 59
| | | | 60
| | | | 61
| | | | 62
| | | | 63
| | | | 64
| | | | 65
| | | | 66
*=Preis anfragen Stückliste.doc | | | EF=Eigenfabrikat BT=Bestellteil PA=Physikartikel NT=Normteil RM=Rohmaterial

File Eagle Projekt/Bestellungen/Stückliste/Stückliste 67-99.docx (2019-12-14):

Produkt | | | | | | Nummer | | Index | Mikro | Blatt/Total
Baugruppe | | | | | | Stück | | Termin | | Auftrag
Erstellt | | Geändert | | | | Felder leer lassen, wird durch PPS ausgefüllt.
Geprüft | | Geprüft
Stk. | Gegenstand/Wert Zchng.Nr. | | Pos.Nr. | Zeile | Bestell-Nr./Material Lieferant | | | | | | C
| | | | 67
| | | | 68
| | | | 69
| | | | 70
| | | | 71
| | | | 72
| | | | 73
| | | | 74
| | | | 75
| | | | 76
| | | | 77
| | | | 78
| | | | 79
| | | | 80
| | | | 81
| | | | 82
| | | | 83
| | | | 84
| | | | 85
| | | | 86
| | | | 87
| | | | 88
| | | | 89
| | | | 90
| | | | 91
| | | | 92
| | | | 93
| | | | 94
| | | | 95
| | | | 96
| | | | 97
| | | | 98
| | | | 99
*=Preis anfragen Stückliste.doc | | | EF=Eigenfabrikat BT=Bestellteil PA=Physikartikel NT=Normteil RM=Rohmaterial

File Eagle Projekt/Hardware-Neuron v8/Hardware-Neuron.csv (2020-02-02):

Qty | Value | Device | Package | Parts | Description | SPICEPREFIX | TP_SIGNAL_NAME
4 | 100n | C-EUC0805 | C0805 | C5, C6, C8, C9 | CAPACITOR, European symbol | C
1 | 10M | R-EU_M0805 | M0805 | R36 | RESISTOR, European symbol | R
3 | 10ME | R-EU_M0805 | M0805 | R7, R8, R22 | RESISTOR, European symbol | R
3 | 10k | R-EU_M0805 | M0805 | R18, R23, R38 | RESISTOR, European symbol | R
6 | 10n | C-EUC0805 | C0805 | C1, C2, C3, C4, C7, C11 | CAPACITOR, European symbol | C
1 | 10u | C-EUC0805 | C0805 | C10 | CAPACITOR, European symbol | C
18 | 1k | R-EU_M0805 | M0805 | R15, R16, R17, R25, R26, R29, R30, R31, R32, R34, R35, R37, R39, R40, R42, R43, R44, R45 | RESISTOR, European symbol | R
18 | 1kE | R-EU_M0805 | M0805 | R1, R2, R3, R4, R5, R6, R9, R10, R11, R12, R13, R14, R19, R20, R21, R24, R27, R28 | RESISTOR, European symbol | R
5 | BAT60J | BAT60J | SOD323_ST | D1, D2, D3, D4, D5 | Schottky barrier diode
7 | BC846 | BC846 | SOT23 | T1, T2, T4, T5, T6, T7, T8 | NPN TRANSISTOR
5 | BCX71SMD | BCX71SMD | SOT23 | Q2, Q3, Q15, Q22, Q23 | PNP Transistor
20 | BSS123 | BSS123 | SOT23 | Q6, Q7, Q8, Q9, Q10, Q11, Q12, Q14, Q16, Q17, Q19, Q21, Q25, Q27, Q28, Q29, Q30, Q31, Q32, Q33 | N-CHANNEL MOS FET
6 | FDN360P | FDN360P | SUPER-SOT3 | Q1, Q4, Q5, Q13, Q18, Q20 | Single P-Channel, PowerTrench (R) MOSFET
2 | PMLL41SOD80C | PMLL41SOD80C | SOD80C | D6, D7 | High-speed diodes
8 | PTR1PAD1-17 | PTR1PAD1-17 | P1-17 | +5V, 0V, EN, S, X0, X1, X2, Y_ | TEST PIN

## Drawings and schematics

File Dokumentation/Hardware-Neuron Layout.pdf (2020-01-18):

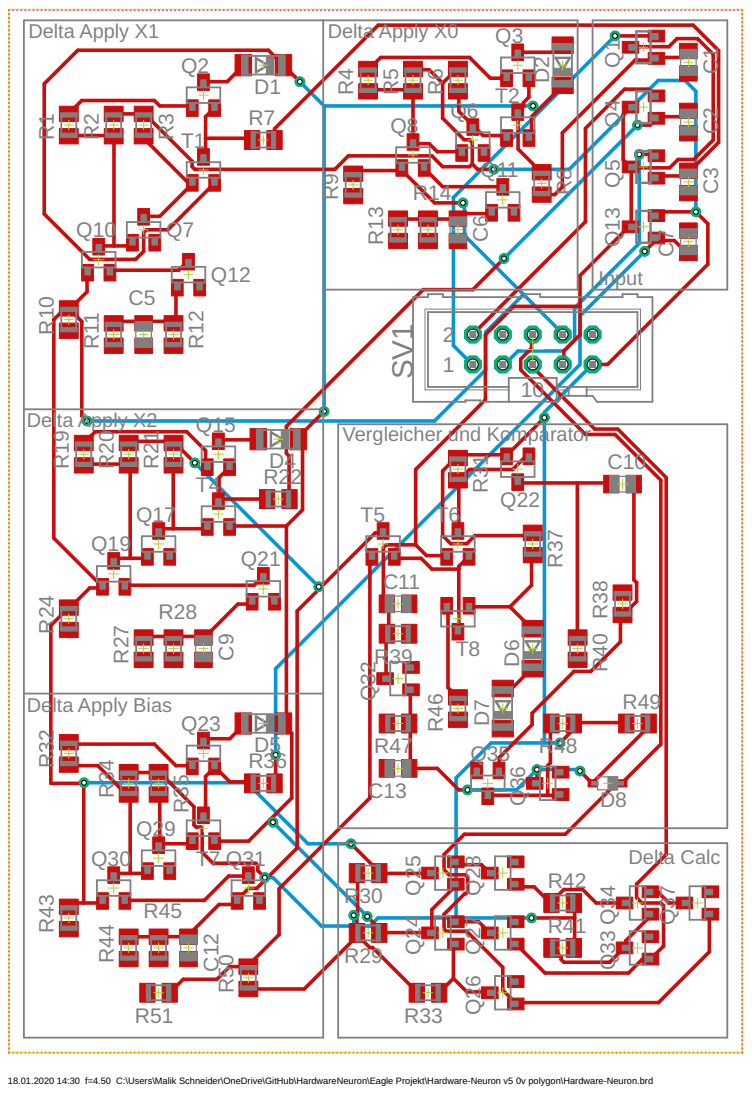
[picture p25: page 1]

18.01.2020 14:30 f=4.50 C:\Users\Malik Schneider\OneDrive\GitHub\HardwareNeuron\Eagle Projekt\Hardware-Neuron v5 0v polygon\Hardware-Neuron.brd

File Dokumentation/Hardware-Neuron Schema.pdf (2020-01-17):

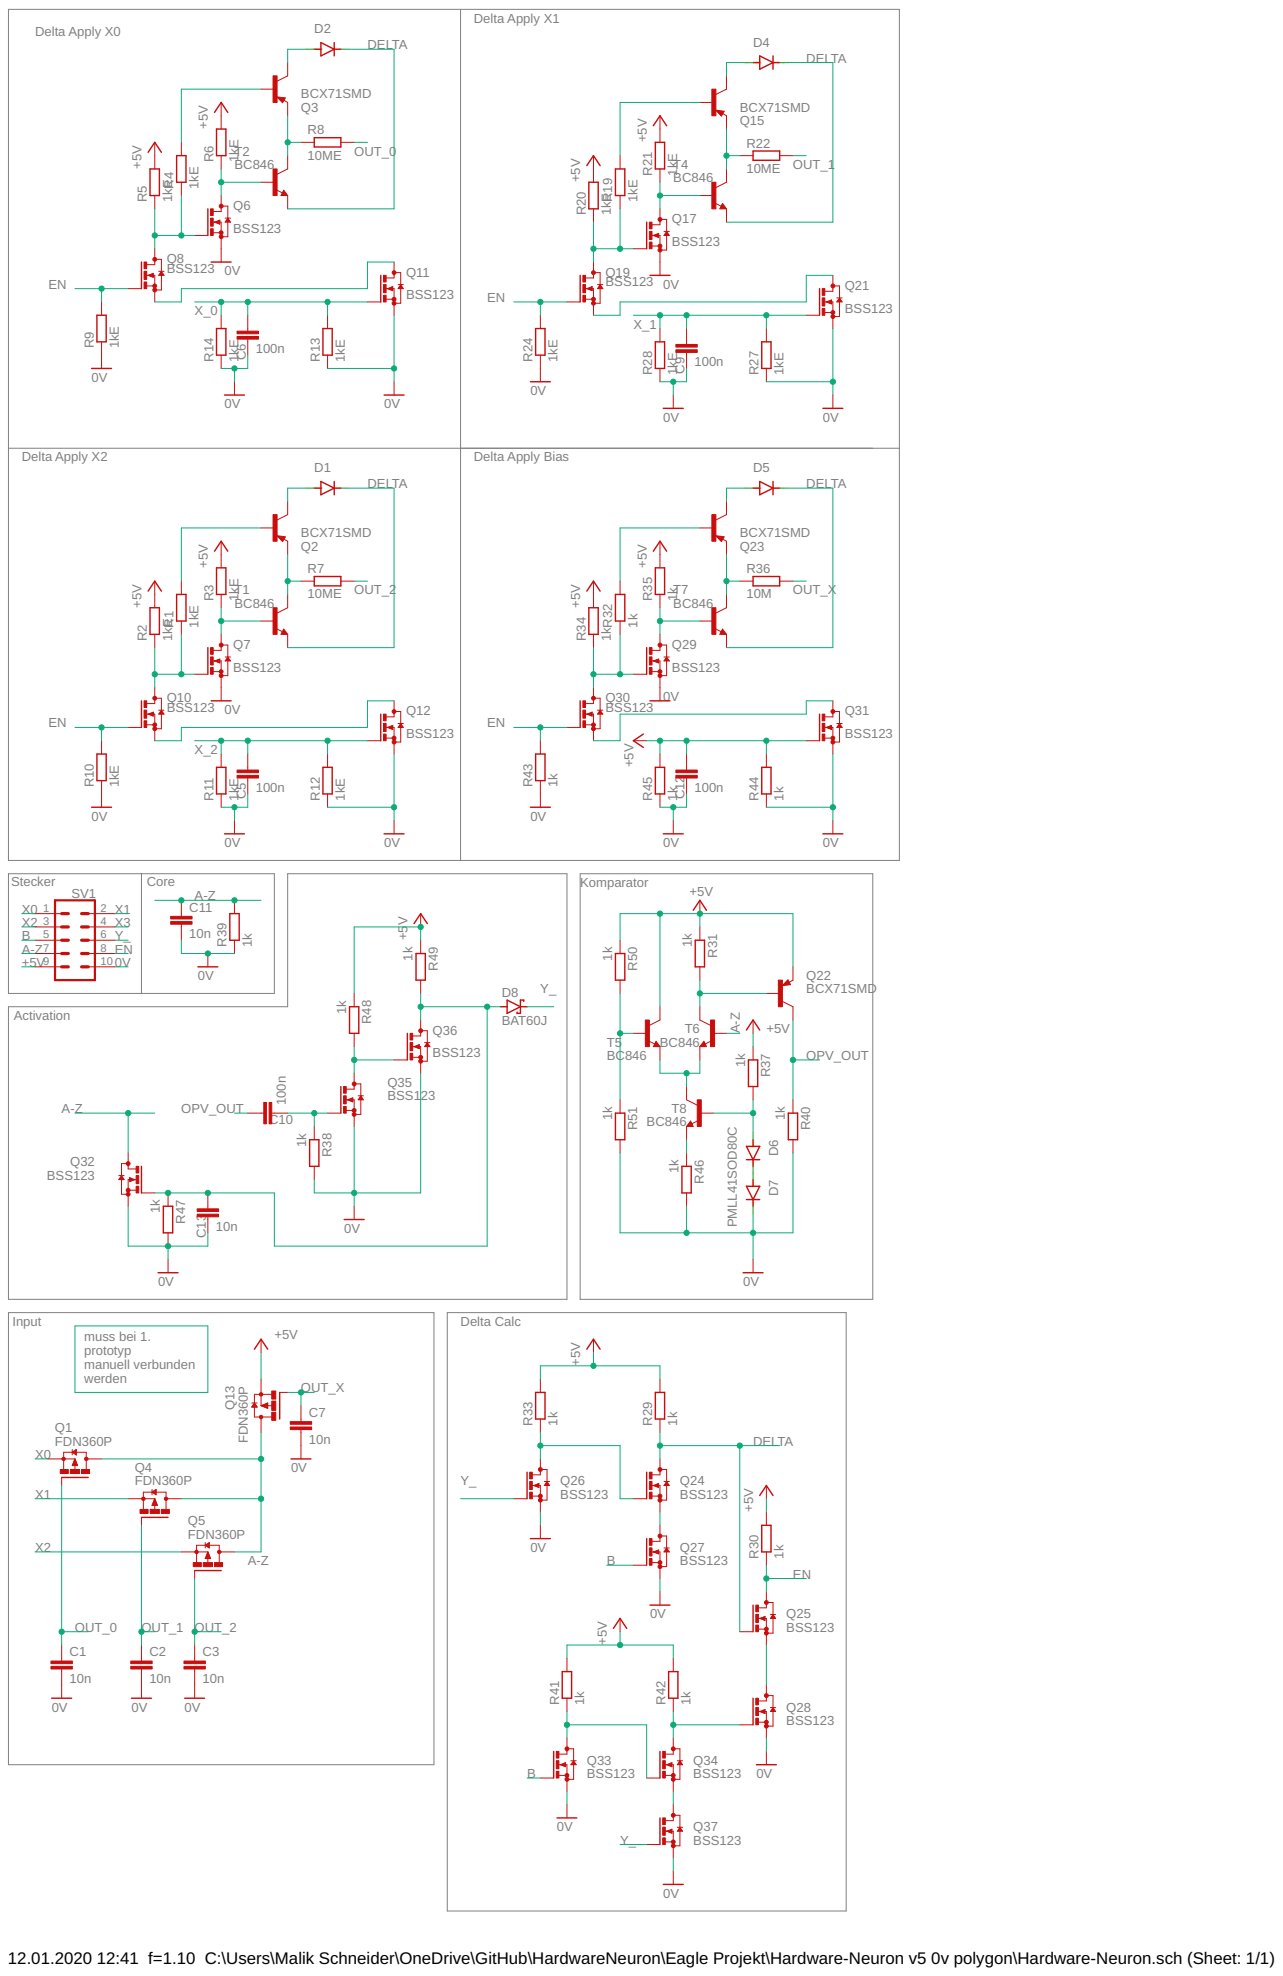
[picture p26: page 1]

SpiceOrder 1 SpiceOrder 2

muss bei 1. prototyp manuell verbunden werden

12.01.2020 12:41 f=1.10 C:\Users\Malik Schneider\OneDrive\GitHub\HardwareNeuron\Eagle Projekt\Hardware-Neuron v5 0v polygon\Hardware-Neuron.sch (Sheet: 1/1)

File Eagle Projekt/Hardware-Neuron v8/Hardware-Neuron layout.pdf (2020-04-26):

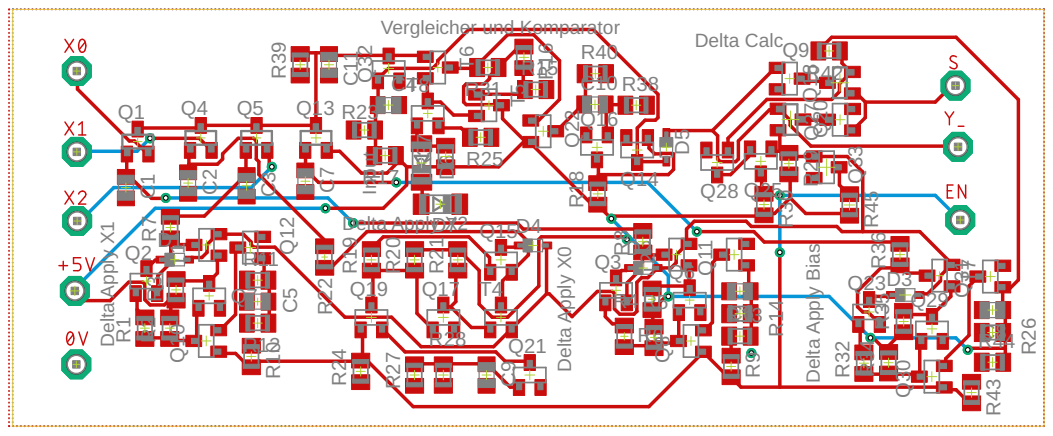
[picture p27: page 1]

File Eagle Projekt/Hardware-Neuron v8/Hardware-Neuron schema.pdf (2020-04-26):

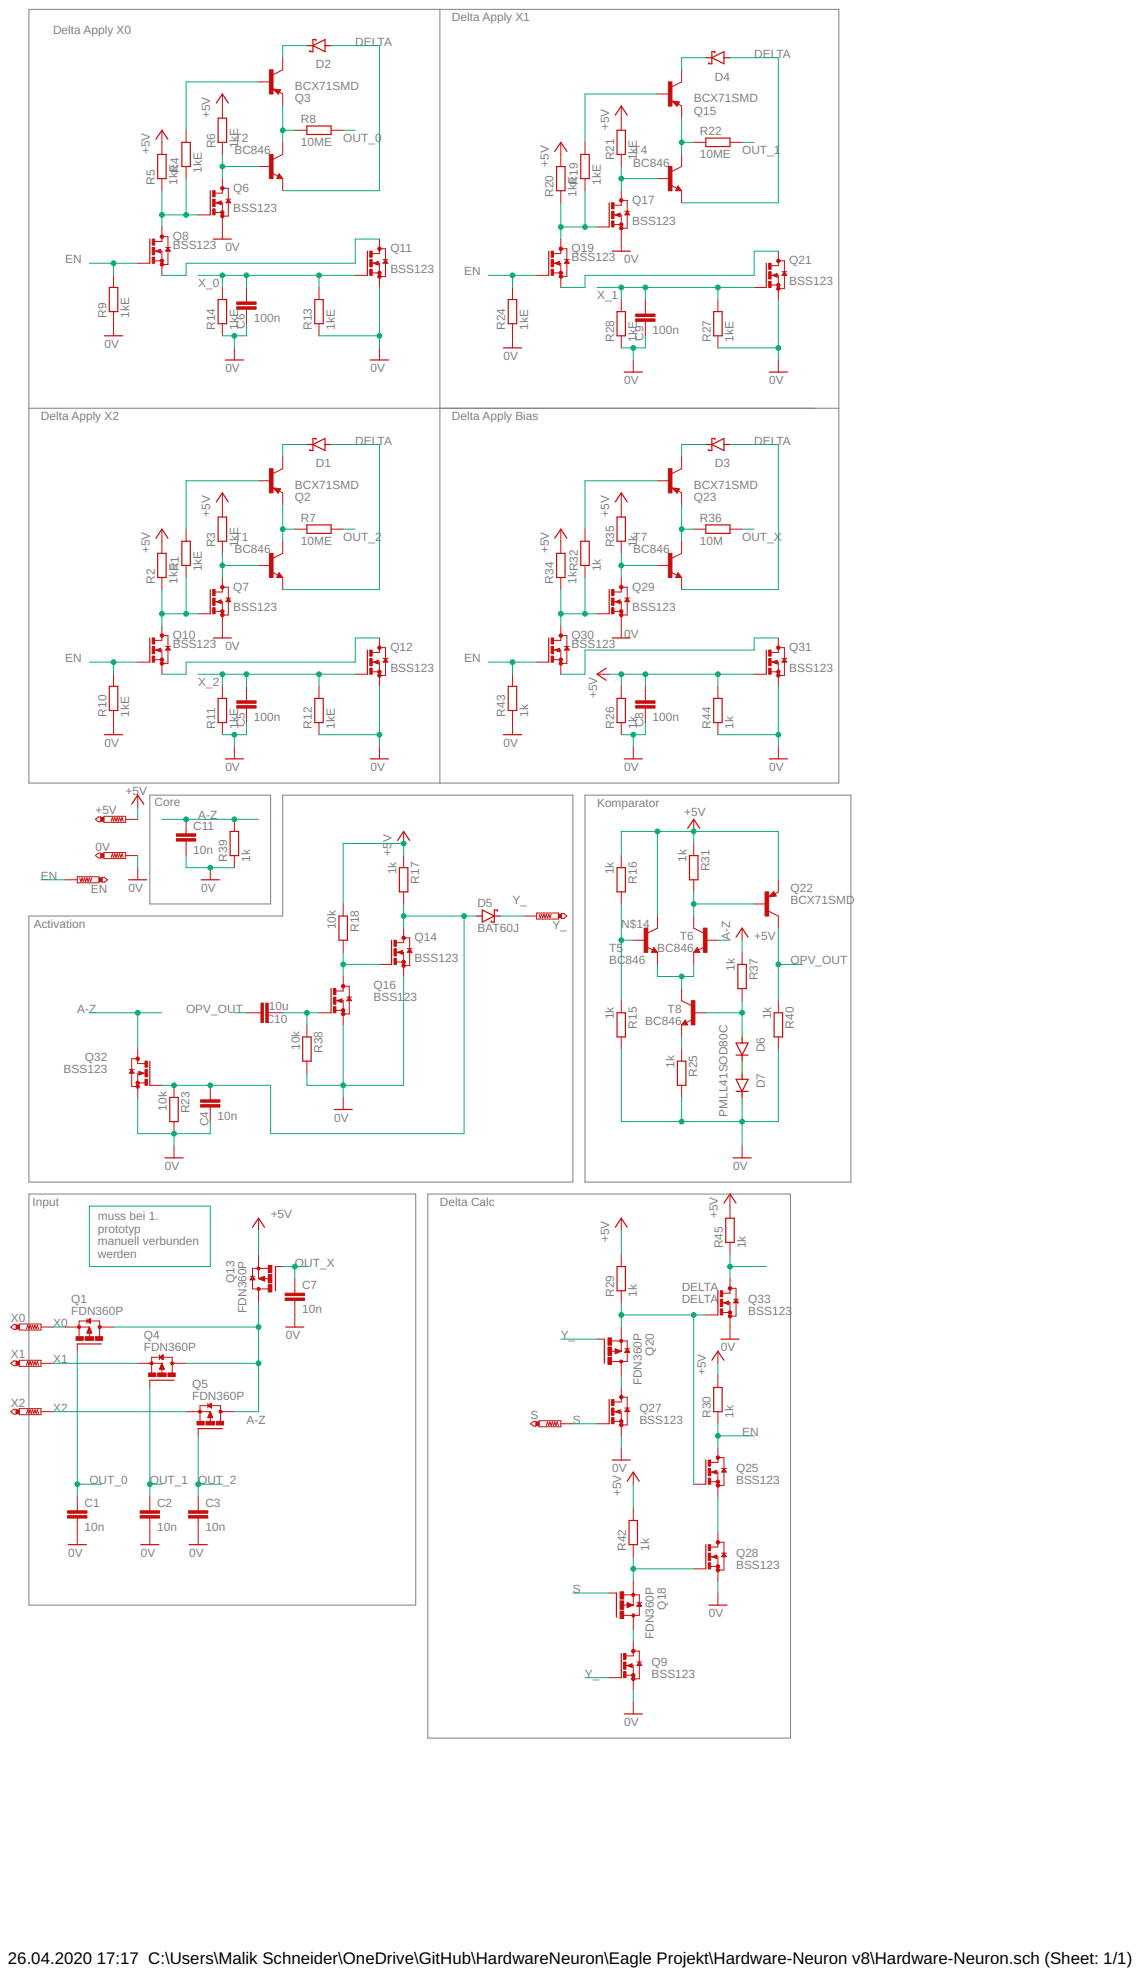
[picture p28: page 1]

SpiceOrder 1 SpiceOrder 2

muss bei 1. prototyp manuell verbunden werden

26.04.2020 17:17 C:\Users\Malik Schneider\OneDrive\GitHub\HardwareNeuron\Eagle Projekt\Hardware-Neuron v8\Hardware-Neuron.sch (Sheet: 1/1)

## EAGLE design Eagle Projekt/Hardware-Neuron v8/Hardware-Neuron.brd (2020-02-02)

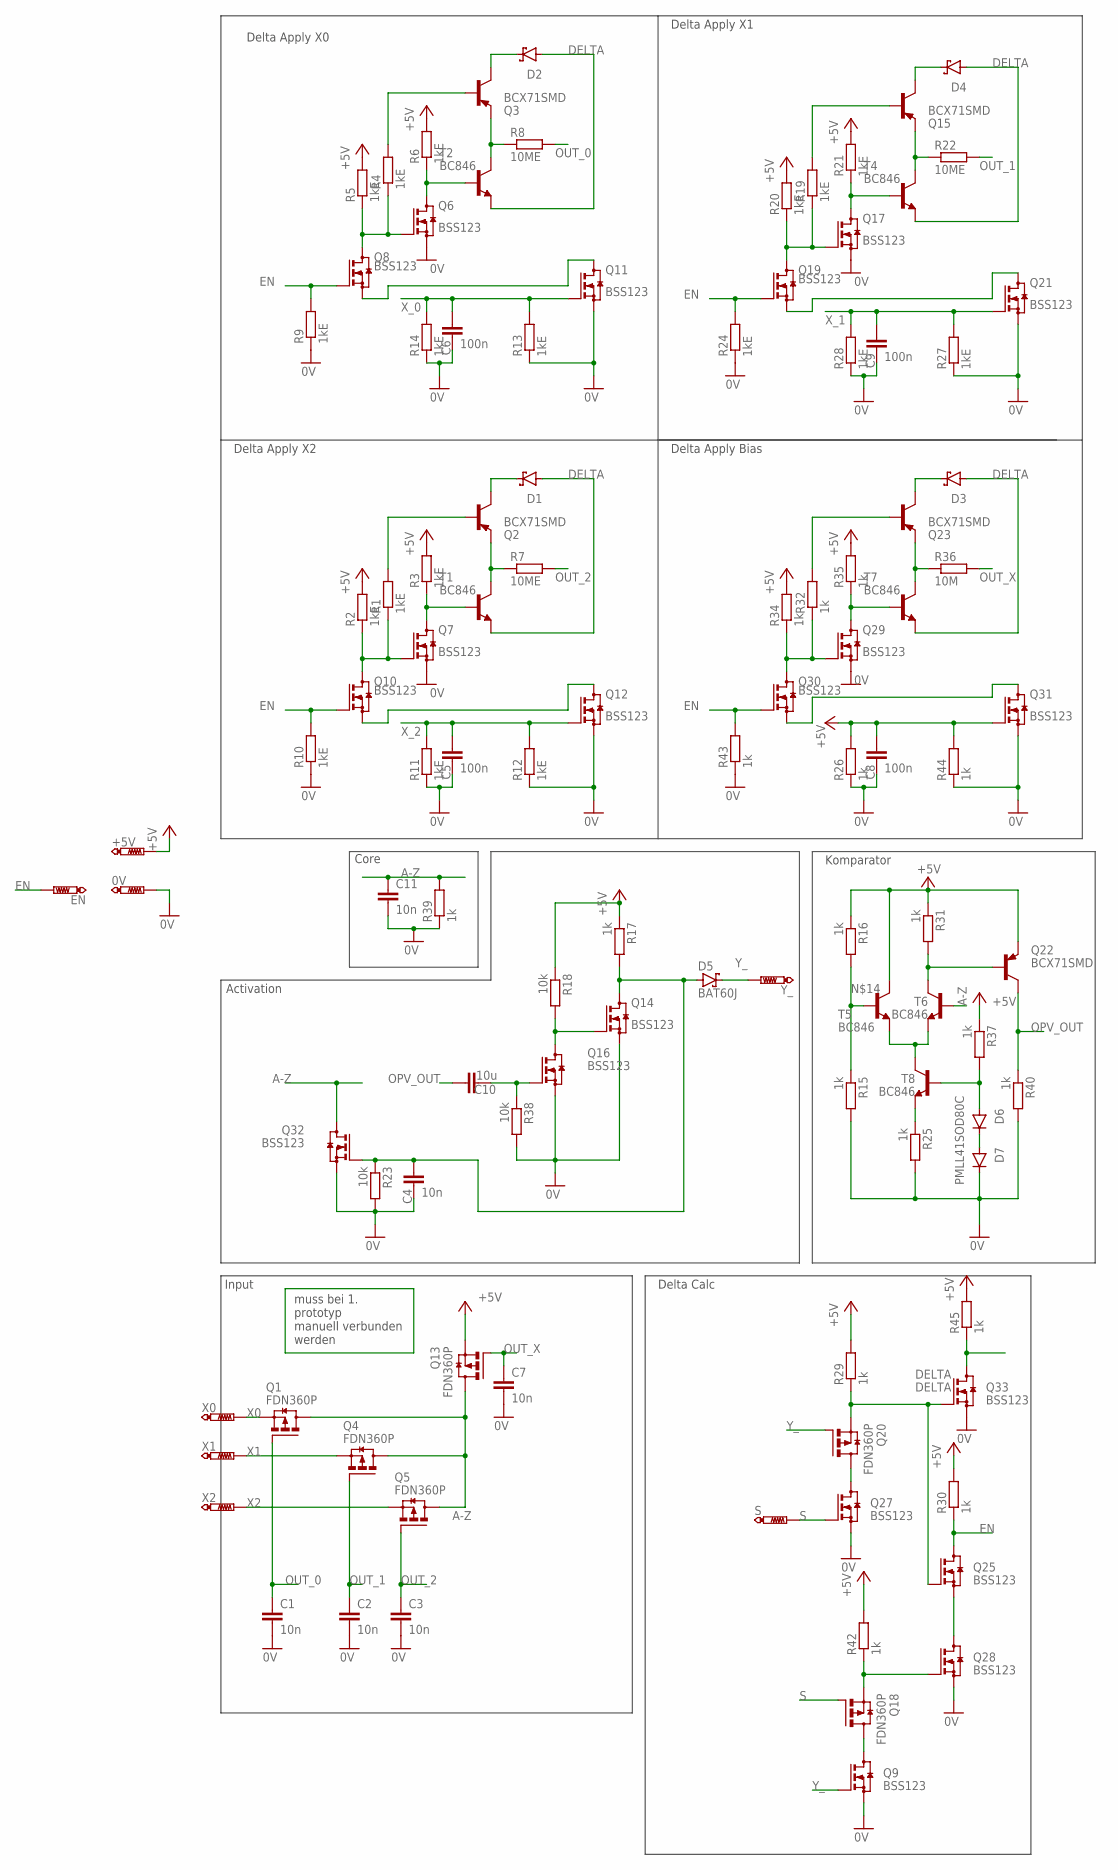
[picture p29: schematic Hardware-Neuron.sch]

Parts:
0V: PTR1PAD1-17; P1-17
+5V: PTR1PAD1-17; P1-17
C1, C2, C3, C4, C7, C11: 10n; C0805
C5, C6, C8, C9: 100n; C0805
C10: 10u; C0805
D1, D2, D3, D4, D5: BAT60J; SOD323_ST
D6, D7: PMLL41SOD80C; SOD80C
EN: PTR1PAD1-17; P1-17
Q1, Q4, Q5, Q13, Q18, Q20: FDN360P; SUPER-SOT3
Q2, Q3, Q15, Q22, Q23: BCX71SMD; SOT23
Q6, Q7, Q8, Q9, Q10, Q11, Q12, Q14, Q16, Q17, Q19, Q21, Q25, Q27, Q28, Q29, Q30, Q31, Q32, Q33: BSS123; SOT23
R1, R2, R3, R4, R5, R6, R9, R10, R11, R12, R13, R14, R19, R20, R21, R24, R27, R28: 1kE; M0805
R7, R8, R22: 10ME; M0805
R15, R16, R17, R25, R26, R29, R30, R31, R32, R34, R35, R37, R39, R40, R42, R43, R44, R45: 1k; M0805
R18, R23, R38: 10k; M0805
R36: 10M; M0805
S: PTR1PAD1-17; P1-17
T1, T2, T4, T5, T6, T7, T8: BC846; SOT23
X0, X1, X2: PTR1PAD1-17; P1-17
Y_: PTR1PAD1-17; P1-17

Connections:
0V: 0V.TP, C1.2, C2.2, C3.2, C4.2, C5.2, C6.2, C7.2, C8.2, C9.2, C11.2, D7.C, Q6.2 (S), Q7.2 (S), Q9.2 (S), Q11.2 (S), Q12.2 (S), Q14.2 (S), Q16.2 (S), Q17.2 (S), Q21.2 (S), Q27.2 (S), Q28.2 (S), Q29.2 (S), Q31.2 (S), Q32.2 (S), Q33.2 (S), R9.1, R10.1, R11.1, R12.1, R13.1, R14.1, R15.2, R23.2, R24.1, R25.2, R26.1, R27.1, R28.1, R38.2, R39.1, R40.2, R43.1, R44.1
+5V: +5V.TP, C8.1, Q13.2 (S), Q22.2 (E), Q31.1 (G), R2.2, R3.2, R5.2, R6.2, R16.1, R17.1, R18.1, R20.2, R21.2, R26.2, R29.2, R30.2, R31.1, R34.2, R35.2, R37.1, R42.2, R44.2, R45.2, T5.3 (C)
A-Z: C11.1, Q1.3 (D), Q4.3 (D), Q5.3 (D), Q13.3 (D), Q32.3 (D), R39.2, T6.1 (B)
DELTA: D1.A, D2.A, D3.A, D4.A, Q20.2 (S), Q25.1 (G), Q33.1 (G), R29.1, T1.2 (E), T2.2 (E), T4.2 (E), T7.2 (E)
EN: EN.TP, Q8.1 (G), Q10.1 (G), Q19.1 (G), Q25.3 (D), Q30.1 (G), R9.2, R10.2, R24.2, R30.1, R43.2
unnamed: Q29.3 (D), R35.1, T7.1 (B)
unnamed: Q23.2 (E), R36.1, T7.3 (C)
unnamed: C10.2, Q16.1 (G), R38.1
unnamed: Q33.3 (D), R45.1
unnamed: Q14.1 (G), Q16.3 (D), R18.2
unnamed: Q6.3 (D), R6.1, T2.1 (B)
unnamed: Q8.2 (S), Q11.3 (D)
unnamed: Q3.2 (E), R8.1, T2.3 (C)
unnamed: D3.C, Q23.3 (C)
unnamed: Q23.1 (B), R32.2
unnamed: Q29.1 (G), Q30.3 (D), R32.1, R34.1
unnamed: Q30.2 (S), Q31.3 (D)
unnamed: D6.C, D7.A
unnamed: R15.1, R16.2, T5.1 (B)
unnamed: C4.1, D5.A, Q14.3 (D), Q32.1 (G), R17.2, R23.1
unnamed: Q9.3 (D), Q18.3 (D)
unnamed: R25.1, T8.2 (E)
unnamed: Q22.1 (B), R31.2, T6.3 (C)
unnamed: T5.2 (E), T6.2 (E), T8.3 (C)
unnamed: Q17.3 (D), R21.1, T4.1 (B)
unnamed: D6.A, R37.2, T8.1 (B)
unnamed: D2.C, Q3.3 (C)
unnamed: Q20.3 (D), Q27.3 (D)
unnamed: Q15.2 (E), R22.1, T4.3 (C)
unnamed: Q3.1 (B), R4.2
unnamed: Q6.1 (G), Q8.3 (D), R4.1, R5.1
unnamed: Q18.2 (S), Q28.1 (G), R42.1
unnamed: D4.C, Q15.3 (C)
unnamed: Q15.1 (B), R19.2
unnamed: Q25.2 (S), Q28.3 (D)
unnamed: Q17.1 (G), Q19.3 (D), R19.1, R20.1
unnamed: Q19.2 (S), Q21.3 (D)
unnamed: Q7.3 (D), R3.1, T1.1 (B)
unnamed: Q2.2 (E), R7.1, T1.3 (C)
unnamed: D1.C, Q2.3 (C)
unnamed: Q2.1 (B), R1.2
unnamed: Q7.1 (G), Q10.3 (D), R1.1, R2.1
unnamed: Q10.2 (S), Q12.3 (D)
OPV_OUT: C10.1, Q22.3 (C), R40.1
OUT_0: C1.1, Q1.1 (G), R8.2
OUT_1: C2.1, Q4.1 (G), R22.2
OUT_2: C3.1, Q5.1 (G), R7.2
OUT_X: C7.1, Q13.1 (G), R36.2
S: Q18.1 (G), Q27.1 (G), S.TP
X0: Q1.2 (S), X0.TP
X1: Q4.2 (S), X1.TP
X2: Q5.2 (S), X2.TP
X_0: C6.1, Q11.1 (G), R13.2, R14.2
X_1: C9.1, Q21.1 (G), R27.2, R28.2
X_2: C5.1, Q12.1 (G), R11.2, R12.2
Y_: D5.C, Q9.1 (G), Q20.1 (G), Y_.TP

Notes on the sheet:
Activation
Core
Input
Delta Calc
Komparator
Delta Apply X0
Delta Apply X1
Delta Apply X2
Delta Apply Bias
muss bei 1. prototyp manuell verbunden werden

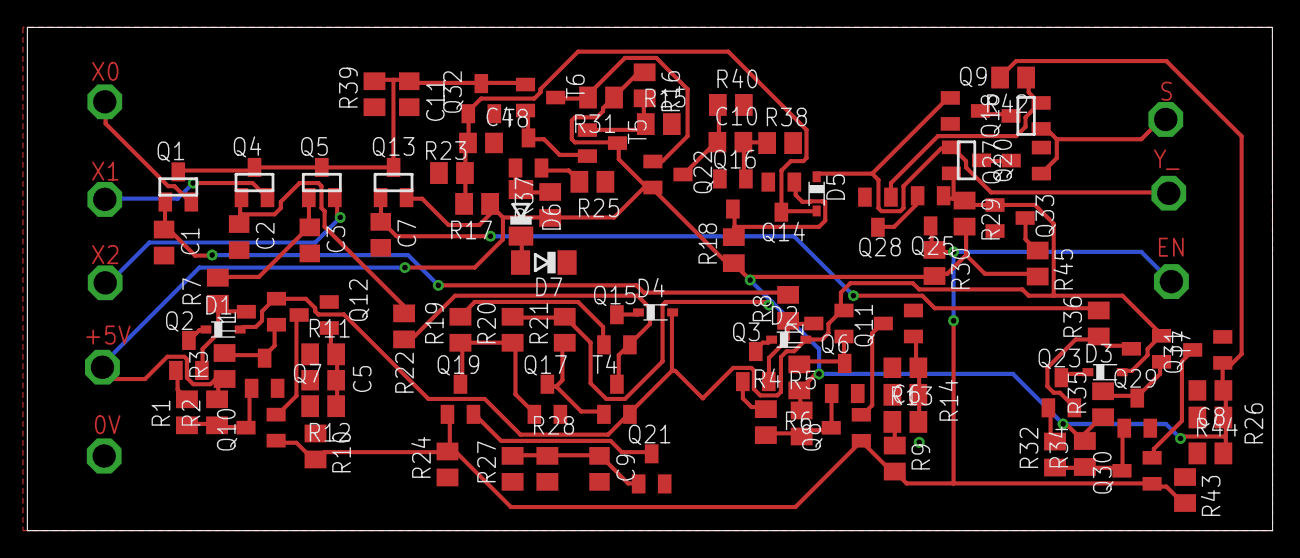
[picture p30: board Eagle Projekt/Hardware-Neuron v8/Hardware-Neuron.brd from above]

Board: 2 copper layers, 91.0 x 36.8 mm, 107 parts (0 on the bottom side), 56 nets.

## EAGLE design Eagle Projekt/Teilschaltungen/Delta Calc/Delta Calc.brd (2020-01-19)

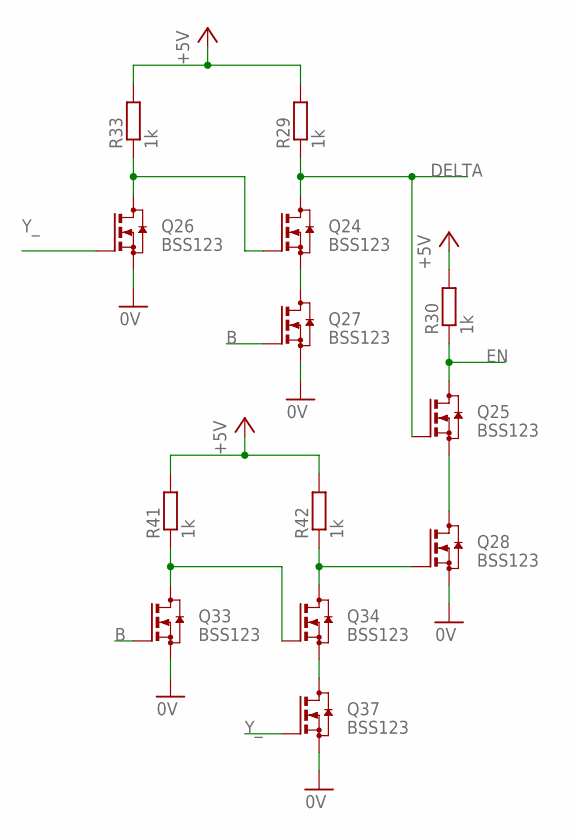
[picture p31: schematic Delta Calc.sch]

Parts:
Q24, Q25, Q26, Q27, Q28, Q33, Q34, Q37: BSS123; SOT23
R29, R30, R33, R41, R42: 1k; M0805

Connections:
0V: Q26.2 (S), Q27.2 (S), Q28.2 (S), Q33.2 (S), Q37.2 (S)
+5V: R29.2, R30.2, R33.2, R41.2, R42.2
B: Q27.1 (G), Q33.1 (G)
DELTA: Q24.3 (D), Q25.1 (G), R29.1
EN: Q25.3 (D), R30.1
unnamed: Q24.1 (G), Q26.3 (D), R33.1
unnamed: Q24.2 (S), Q27.3 (D)
unnamed: Q28.1 (G), Q34.3 (D), R42.1
unnamed: Q33.3 (D), Q34.1 (G), R41.1
unnamed: Q25.2 (S), Q28.3 (D)
unnamed: Q34.2 (S), Q37.3 (D)
Y_: Q26.1 (G), Q37.1 (G)

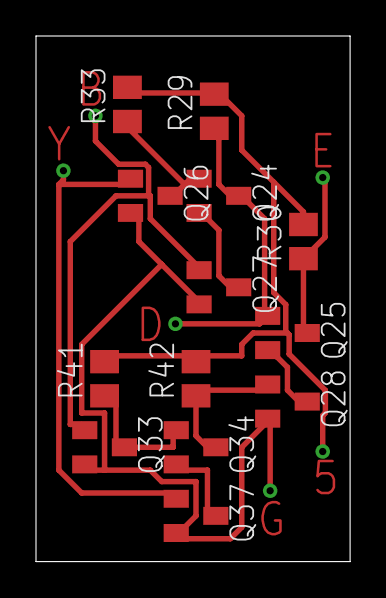
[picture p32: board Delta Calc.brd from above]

Board: 2 copper layers, 17.4 x 29.2 mm, 13 parts (0 on the bottom side), 12 nets.

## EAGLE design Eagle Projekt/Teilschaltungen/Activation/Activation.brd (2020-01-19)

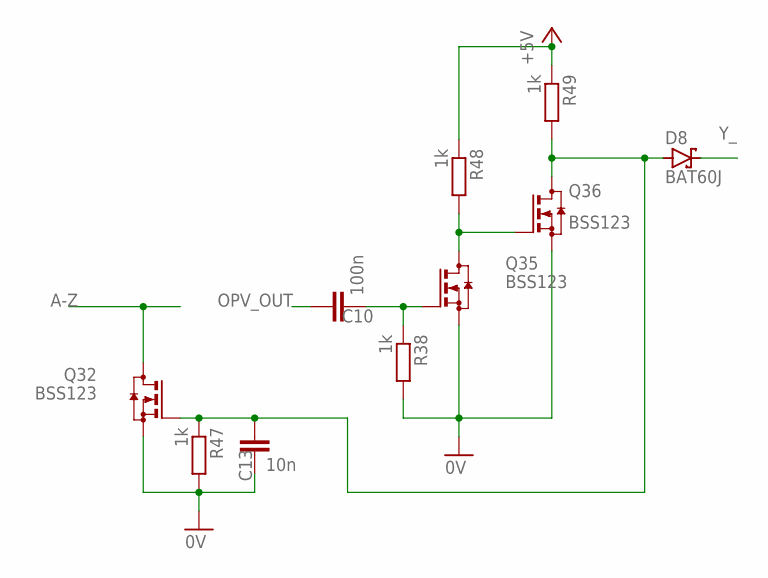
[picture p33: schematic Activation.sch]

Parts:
C10: 100n; C0805
C13: 10n; C0805
D8: BAT60J; SOD323_ST
Q32, Q35, Q36: BSS123; SOT23
R38, R47, R48, R49: 1k; M0805

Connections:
0V: C13.2, Q32.2 (S), Q35.2 (S), Q36.2 (S), R38.2, R47.2
+5V: R48.1, R49.1
A-Z: Q32.3 (D)
unnamed: C10.2, Q35.1 (G), R38.1
unnamed: Q35.3 (D), Q36.1 (G), R48.2
unnamed: C13.1, D8.A, Q32.1 (G), Q36.3 (D), R47.1, R49.2
OPV_OUT: C10.1
Y_: D8.C

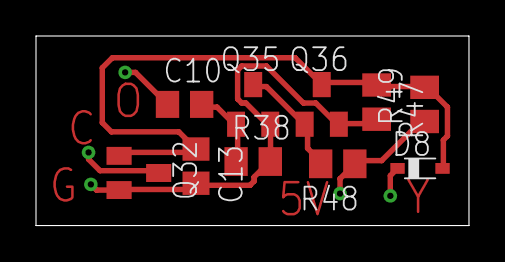
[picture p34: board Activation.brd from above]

Board: 2 copper layers, 24.1 x 10.5 mm, 10 parts (0 on the bottom side), 5 nets.

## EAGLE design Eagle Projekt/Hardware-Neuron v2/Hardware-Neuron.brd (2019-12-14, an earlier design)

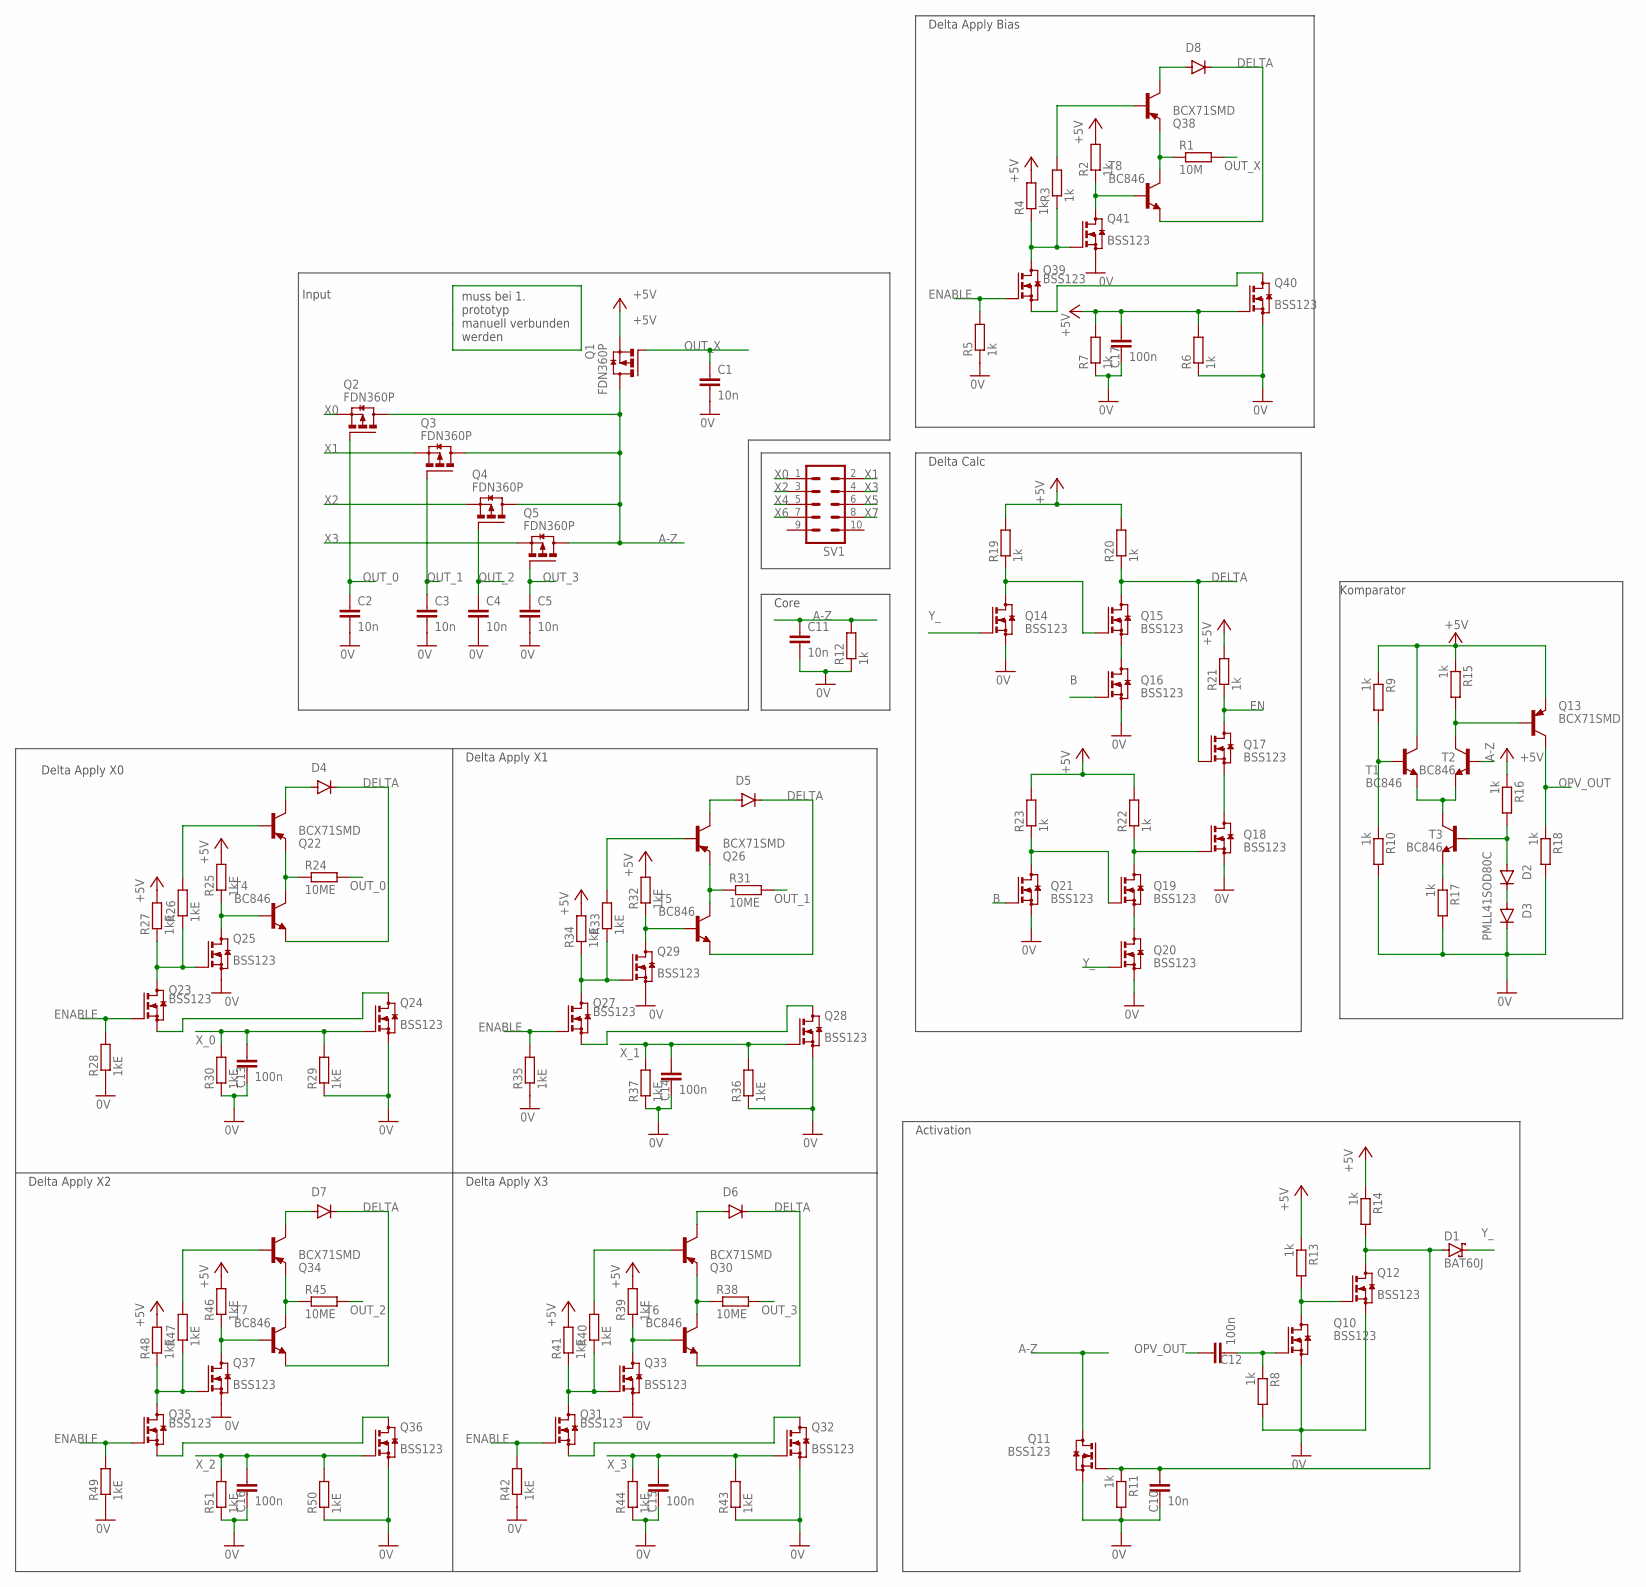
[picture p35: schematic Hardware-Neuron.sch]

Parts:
C1, C2, C3, C4, C5, C10, C11: 10n; C1206
C12, C13, C14, C15, C16, C17: 100n; C1206
D1: BAT60J; SOD323_ST
D2, D3, D4, D5, D6, D7, D8: PMLL41SOD80C; SOD80C
Q1, Q2, Q3, Q4, Q5: FDN360P; SUPER-SOT3
Q10, Q11, Q12, Q14, Q15, Q16, Q17, Q18, Q19, Q20, Q21, Q23, Q24, Q25, Q27, Q28, Q29, Q31, Q32, Q33, Q35, Q36, Q37, Q39, Q40, Q41: BSS123; SOT23
Q13, Q22, Q26, Q30, Q34, Q38: BCX71SMD; SOT23
R1: 10M; R1206
R2, R3, R4, R5, R6, R7, R8, R9, R10, R11, R12, R13, R14, R15, R16, R17, R18, R19, R20, R21, R22, R23: 1k; R1206
R24, R31, R38, R45: 10ME; R1206
R25, R26, R27, R28, R29, R30, R32, R33, R34, R35, R36, R37, R39, R40, R41, R42, R43, R44, R46, R47, R48, R49, R50, R51: 1kE; R1206
SV1: ML10
T1, T2, T3, T4, T5, T6, T7, T8: BC846; SOT23

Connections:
0V: C1.2, C2.2, C3.2, C4.2, C5.2, C10.2, C11.2, C13.2, C14.2, C15.2, C16.2, C17.2, D3.C, Q10.2 (S), Q11.2 (S), Q12.2 (S), Q14.2 (S), Q16.2 (S), Q18.2 (S), Q20.2 (S), Q21.2 (S), Q24.2 (S), Q25.2 (S), Q28.2 (S), Q29.2 (S), Q32.2 (S), Q33.2 (S), Q36.2 (S), Q37.2 (S), Q40.2 (S), Q41.2 (S), R5.1, R6.1, R7.1, R8.2, R10.2, R11.2, R12.1, R17.2, R18.2, R28.1, R29.1, R30.1, R35.1, R36.1, R37.1, R42.1, R43.1, R44.1, R49.1, R50.1, R51.1
+5V: C17.1, Q1.2 (S), Q13.2 (E), Q40.1 (G), R2.2, R4.2, R6.2, R7.2, R9.1, R13.1, R14.1, R15.1, R16.1, R19.2, R20.2, R21.2, R22.2, R23.2, R25.2, R27.2, R32.2, R34.2, R39.2, R41.2, R46.2, R48.2, T1.3 (C)
A-Z: C11.1, Q1.3 (D), Q2.3 (D), Q3.3 (D), Q4.3 (D), Q5.3 (D), Q11.3 (D), R12.2, T2.1 (B)
B: Q16.1 (G), Q21.1 (G)
DELTA: D4.C, D5.C, D6.C, D7.C, D8.C, Q15.3 (D), Q17.1 (G), R20.1, T4.2 (E), T5.2 (E), T6.2 (E), T7.2 (E), T8.2 (E)
EN: Q17.3 (D), R21.1
ENABLE: Q23.1 (G), Q27.1 (G), Q31.1 (G), Q35.1 (G), Q39.1 (G), R5.2, R28.2, R35.2, R42.2, R49.2
unnamed: Q41.3 (D), R2.1, T8.1 (B)
unnamed: Q38.2 (E), R1.1, T8.3 (C)
unnamed: C12.2, Q10.1 (G), R8.1
unnamed: C10.1, D1.A, Q11.1 (G), Q12.3 (D), R11.1, R14.2
unnamed: Q10.3 (D), Q12.1 (G), R13.2
unnamed: Q25.3 (D), R25.1, T4.1 (B)
unnamed: Q23.2 (S), Q24.3 (D)
unnamed: Q22.2 (E), R24.1, T4.3 (C)
unnamed: D8.A, Q38.3 (C)
unnamed: Q38.1 (B), R3.2
unnamed: Q39.3 (D), Q41.1 (G), R3.1, R4.1
unnamed: Q39.2 (S), Q40.3 (D)
unnamed: D2.C, D3.A
unnamed: R9.2, R10.1, T1.1 (B)
unnamed: R17.1, T3.2 (E)
unnamed: Q13.1 (B), R15.2, T2.3 (C)
unnamed: T1.2 (E), T2.2 (E), T3.3 (C)
unnamed: Q29.3 (D), R32.1, T5.1 (B)
unnamed: D2.A, R16.2, T3.1 (B)
unnamed: Q14.3 (D), Q15.1 (G), R19.1
unnamed: D4.A, Q22.3 (C)
unnamed: Q15.2 (S), Q16.3 (D)
unnamed: Q26.2 (E), R31.1, T5.3 (C)
unnamed: Q22.1 (B), R26.2
unnamed: Q23.3 (D), Q25.1 (G), R26.1, R27.1
unnamed: Q18.1 (G), Q19.3 (D), R22.1
unnamed: Q19.1 (G), Q21.3 (D), R23.1
unnamed: D5.A, Q26.3 (C)
unnamed: Q26.1 (B), R33.2
unnamed: Q17.2 (S), Q18.3 (D)
unnamed: Q27.3 (D), Q29.1 (G), R33.1, R34.1
unnamed: Q27.2 (S), Q28.3 (D)
unnamed: Q19.2 (S), Q20.3 (D)
unnamed: Q33.3 (D), R39.1, T6.1 (B)
unnamed: Q30.2 (E), R38.1, T6.3 (C)
unnamed: D6.A, Q30.3 (C)
unnamed: Q30.1 (B), R40.2
unnamed: Q31.3 (D), Q33.1 (G), R40.1, R41.1
unnamed: Q31.2 (S), Q32.3 (D)
unnamed: Q37.3 (D), R46.1, T7.1 (B)
unnamed: Q34.2 (E), R45.1, T7.3 (C)
unnamed: D7.A, Q34.3 (C)
unnamed: Q34.1 (B), R47.2
unnamed: Q35.3 (D), Q37.1 (G), R47.1, R48.1
unnamed: Q35.2 (S), Q36.3 (D)
OPV_OUT: C12.1, Q13.3 (C), R18.1
OUT_0: C2.1, Q2.1 (G), R24.2
OUT_1: C3.1, Q3.1 (G), R31.2
OUT_2: C4.1, Q4.1 (G), R45.2
OUT_3: C5.1, Q5.1 (G), R38.2
OUT_X: C1.1, Q1.1 (G), R1.2
X0: Q2.2 (S), SV1.1
X1: Q3.2 (S), SV1.2
X2: Q4.2 (S), SV1.3
X3: Q5.2 (S), SV1.4
X4: SV1.5
X5: SV1.6
X6: SV1.7
X7: SV1.8
X_0: C13.1, Q24.1 (G), R29.2, R30.2
X_1: C14.1, Q28.1 (G), R36.2, R37.2
X_2: C16.1, Q36.1 (G), R50.2, R51.2
X_3: C15.1, Q32.1 (G), R43.2, R44.2
Y_: D1.C, Q14.1 (G), Q20.1 (G)

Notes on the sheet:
Activation
Core
Input
Delta Calc
Komparator
Delta Apply X0
Delta Apply X1
Delta Apply X2
Delta Apply X3
Delta Apply Bias
muss bei 1. prototyp manuell verbunden werden

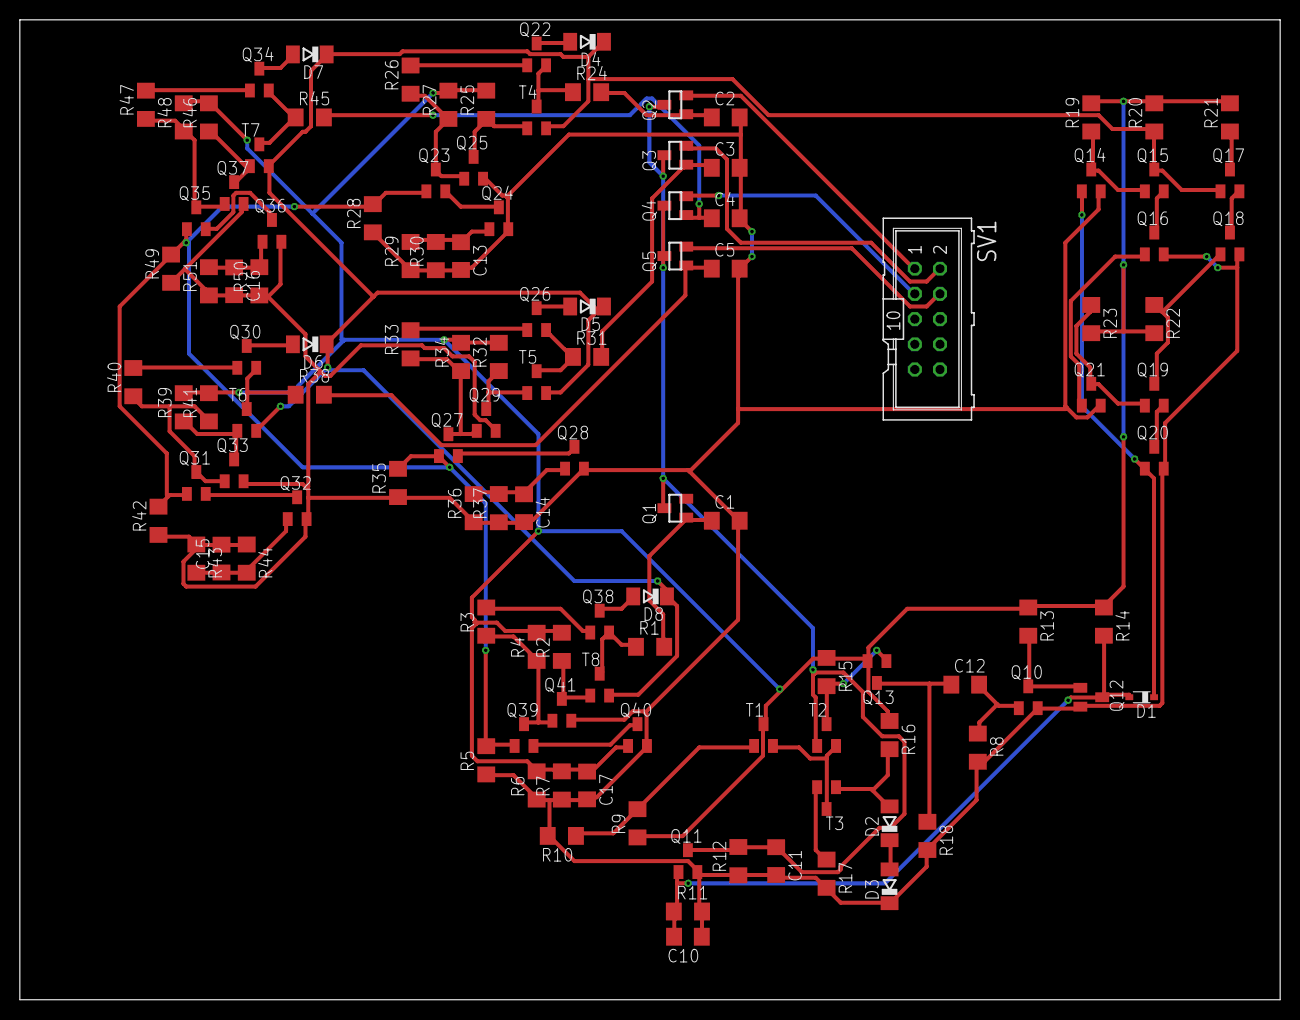
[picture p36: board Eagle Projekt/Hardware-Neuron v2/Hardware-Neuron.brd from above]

Board: 2 copper layers, 127.0 x 98.7 mm, 118 parts (0 on the bottom side), 67 nets.

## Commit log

2019-11-02 First Push
    Project Staring up
    [Hardware-Neuron.sch, NeuronCell_simulation.xlsx]
2019-11-02 Moved File
    [NeuronCell_simulation.xlsx]
2019-11-02 moved files
    [Hardware-Neuron.brd, Hardware-Neuron.sch]
2019-11-02 updated v2
    [Hardware-Neuron.brd, Hardware-Neuron.sch]
2019-11-02 changed v2
    [Hardware-Neuron.brd, Hardware-Neuron.sch]
2019-11-09 titelblatt + layout
    [Hardware-Neuron.brd, Hardware-Neuron.sch]
2019-11-23 malik aar und eagle
    [Hardware-Neuron.brd, Hardware-Neuron.sch]
2019-11-23 überarbeitet
    [Hardware-Neuron.brd, Hardware-Neuron.sch]
2019-11-24 layout angepasst
    [Hardware-Neuron.brd, Hardware-Neuron.sch]
2019-11-25 Eagle Korrektur
    (Nur oberflächlich)
    [Hardware-Neuron.brd, Hardware-Neuron.sch]
2019-11-30 Cosmetics
    Eagle Kontrolliert, Dokumente geortnet
    [Hardware-Neuron.brd, Hardware-Neuron.sch]
2019-12-14 verschönerung in v3
    [Hardware-Neuron.brd, Hardware-Neuron.sch]
2020-01-05 Update von V4
    Schwierig
    [Hardware-Neuron.csv]
2020-01-09 stückliste
    [Hardware-Neuron.csv, Hardware-Neuron.xlsx]
2020-01-09 Layout upgrade
    [Hardware-Neuron.brd, Hardware-Neuron.csv, Hardware-Neuron.sch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]
2020-01-19 zügs
    [Activation.brd, Activation.sch, Delta Calc.brd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]
2020-01-21 Anpassung der Dokumentation
2020-01-22 stückliste und so
    [Hardware-Neuron.brd, Hardware-Neuron.csv, Hardware-Neuron.sch]
2020-02-02 Verschönerung des Kommentars
